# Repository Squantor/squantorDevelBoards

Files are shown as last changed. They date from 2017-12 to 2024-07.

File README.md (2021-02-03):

# Various development boards
This project contains a bunch of various development boards I use in my projects. They are usually focused on learning how to use a specific type of microcontroller or application.
## Nuclone development board series
As the name implies they resemble the [ST nucleo](https://www.st.com/en/evaluation-tools/stm32-nucleo-boards.html) in shape and function, minimal evaluation boards with all pins broken out and lot of jumpers.
## Structure
* [electronics](electronics/) contains the various nuclone examples, they are mostly [LPC microcontrollers](https://www.nxp.com/products/processors-and-microcontrollers/arm-microcontrollers/general-purpose-mcus:GENERAL-PURPOSE-MCUS) from [NXP](https://www.nxp.com/) but a few STM32's, nordic and holtek ARM microcontrollers are planned too.
* [software](software/) some example projects or project templates
* [mechanical](mechanical/) contains drawings for project boxes of the nuclone boards
## Checking out
This project makes extensive use of submodules, use ```git clone --recurse-submodules https://github.com/Squantor/squantorDevelBoards.git``` to clone the repository and its submodules in one go.

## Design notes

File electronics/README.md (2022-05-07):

# Development board electronics
Stored here is the electronics for various development boards I use. Most are based on the "nuclone" principle. They look a lot like the STM32 nucleo series development boards.
## List of boards
* [nuclone board for the LPC804M101JHI33](nuclone_LPC804M101JHI33/README.md) is a breakout for the LPC804M101JHI33 microcontroller.
* [nuclone board for the LPC812M101JDH20](nuclone_LPC812M101JDH20/README.md) is a breakout for the LPC812M101JDH20 microcontroller.
* [nuclone board for the LPC824M201JDH20](nuclone_LPC824M201JDH20/README.md) is a breakout for the LPC824M201JDH20 microcontroller.
* [nuclone board for the LPC824M201JHI33](nuclone_LPC824M201JHI33/README.md) is a breakout for the LPC824M201JHI33 microcontroller.
* [nuclone board for the LPC844M201BD64](nuclone_LPC844M201BD64/README.md) is a breakout for the LPC844M201BD64 microcontroller.
* [nuclone board for the LPC845M301JBD48](nuclone_LPC845M301JBD48/README.md) is a breakout for the LPC845M301JBD48 microcontroller.
* [nuclone board for the LPC1114JBD48](nuclone_LPC1114JBD48/README.md) is a breakout for the LPC1114JBD48 microcontroller.
* [nuclone board for the LPC1125JBD48](nuclone_LPC1125JBD48/README.md) is a breakout for the LPC1125JBD48 microcontroller.
* [nuclone board for the STM32F030C8T6](nuclone_STM32F030C8T6/README.md) is a breakout for the STM32F030C8T6 microcontroller.
* [nuclone board for the STM32F030K6](nuclone_STM32F030K6/README.md) is a breakout for the STM32F030K6 microcontroller.
* [nuclone board for the STM32F031K6](nuclone_STM32F031K6/README.md) is a breakout for the STM32F031K6 microcontroller.
* [small nuclone universal expansion board with USB to UART and prototyping area](nuclone_small_uart_expansion/README.md).
* [LPC824M201JHI33 nuclone expansion board with SD card slot](nuclone_LPC824M201JHI33_expansion_microSD_card/README.md).
* [LPC824M201JHI33 nuclone expansion board with SOIC NOR Flash](nuclone_LPC824M201JHI33_expansion_serial_flash_SOIC/README.md).
* [LPC824M201JHI33 nuclone expansion board with USON NOR Flash](nuclone_LPC824M201JHI33_expansion_serial_flash_USON/README.md).
* [LPC824M201JHI33 nuclone expansion board with wearable prototyping circuit](nuclone_LPC824M201JHI33_expansion_wearable/README.md). This contains a battery charger, serial flash for datalogging, usb connection for data download and a few sensors like accelerometer, ambient light and a few more. (WIP)

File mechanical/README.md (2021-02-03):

# Squantor Development boards mechanical components
Here reside the mechanical components the squantor development boards
## Descriptions
* [Small nuclone box base](small_nuclone_base_plate/): base plate for the small sized nuclone boards.
* Small nuclone box cover low: cover going over the small nuclone box base, having holes for the pin headers.
* Small nuclone box cover medium: cover going over the small nuclone box base, higher to accomodate one expansion board.
* Medium nuclone box base: base plate for the medium sized nuclone boards.
* Medium nuclone box cover low: cover going over the medium nuclone box base, having holes for the pin headers.
* Medium nuclone box cover medium: cover going over the medium nuclone box base, higher to accomodate one expansion board.

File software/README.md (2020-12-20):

# Squantor Development board software
Here are all the software projects used to exercise, test and just use the squantor development boards. The nuclone boards in particular.
## Project list
Here is a list of the various projects.
* LPC824_template: template project used for LPC824 microcontrollers, handy copy and paste reference
* nuclone_LPC824M201JHI33_expansion_serial_flash: demonstrator project for using the serial flash expansion board on a nuclone LPC824M201JHI33 development board
* PC: empty PC template
## Compiling
There are multiple projects present in this directory. Invoking compilation of any project is done with the ```PROJECT``` variable that needs to be passed on, see the following example:
```
make PROJECT=LPC824_template
```
Building can be done with various configurations that set up flags and other settings, this configuration is set with the ```CONFIG``` variable. Most projects have the ```release``` and ```debug``` where the ```debug``` configuration is default.
The ```release``` configuration has optimizations enabled (usually for size) and minimal included debugging information. The ```debug``` configuration has NO optimization and full debugging information. There might be specific configurations available per project. When no ```CONFIG``` is defined the default is the ```debug``` configuration.
### Debugging embedded projects
For debugging on embedded targets, the [Black Magic Probe](https://github.com/blacksphere/blackmagic/wiki) is used, scripts to use this debugger are present in the ```gdb_scripts``` directory. make can be used to invoke debugging:
```
make PROJECT=LPC824_template gdbbmp
```
If a build is needed, it is done automatically.
```
make tpwrdisable
make tpwrenable
```
The black magic probe is capable of powering the target, these commands enable/disable this function.
### Depedencies
The templates have a few dependencies that are automatically cloned when you do a clone with ```--recurses-submodules
* squantorLibC for minimal LibC functionality
* squantorLibEmbeddedC for various embedded helper functions
* squantorLibEmbedded newer embedded helper functions library
## Usage
To use the software you need the following hardware:
* [Black magic probe](https://github.com/blacksphere/blackmagic)
* Describe additional electronics prerequisites
# Additional information
If the project needs further explanation like commands, theory of operation or something else, Describe it here.
# TODO
Open tasks still to complete.
* completing this readme

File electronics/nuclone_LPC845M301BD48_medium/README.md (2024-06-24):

# medium nuclone board LPC845 PQFP48
Medium sized nuclone board LPC845 PQFP48
## TODO's
Still some things need to be done:
* schematic entry 
* PCB layout
* Review with one night in between
* Produce at [OSHPARK](https://oshpark.com/)
* Assemble
* Test & characterise
* update Readme.md with pictures and BOM
## BOM

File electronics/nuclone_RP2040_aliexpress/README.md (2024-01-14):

# nuclone raspberry pi pico
Medium sized nuclone fitted with a raspberry pi pico soldered on board, the pico micro USB is used as the board connection.
# HSI (Hardware Software Interface)
## TODO's
Still some things need to be done:
* schematic entry 
* PCB layout
* Review with one night in between
* Produce at [OSHPARK](https://oshpark.com/)
* Assemble
* Test & characterise
* update Readme.md with pictures and BOM
## BOM
* Raspberry pi pico
## Pictures

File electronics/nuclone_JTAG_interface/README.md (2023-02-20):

# Nuclone JTAG interface
Nuclone JTAG interface
# HSI (Hardware Software Interface)
You need to hook up the wanted pins to the nuclone pins, below is a list of test points you can connect to.
* UART RX
* UART TX
TODO JTAG
## TODO's
Still some things need to be done:
* Fill in this project description
* schematic entry 
* PCB layout
* Review with one night in between
* Produce at [aisler](https://aisler.net/)
* Assemble
* Test & characterise
* update Readme.md with pictures and BOM
## BOM
* TODO 1 bit dual supply level shifter
## Pictures
TODO

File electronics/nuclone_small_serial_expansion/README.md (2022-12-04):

# Nuclone expansion board with FTDI/UART connection
Nuclone expansion board with UART connection, prototyping area and some connections
# HSI (Hardware Software Interface)
No real HSI, UART RX/TX brought outside
## TODO's
Still some things need to be done:
* schematic entry 
* PCB layout
* Review with one night in between
* Produce at [OSHPARK](https://oshpark.com/)
* Assemble
* Test & characterise
* update Readme.md with pictures and BOM
## BOM
* bunch of JST-PH connectors

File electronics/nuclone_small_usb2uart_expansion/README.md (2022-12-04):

# Nuclone UART, JST expansion board
Nuclone expansion board with UART, prototyping area and some connections
# HSI (Hardware Software Interface)
No real HSI to speak about.
## TODO's
Still some things need to be done:
* update Readme.md with pictures and BOM
## BOM
This is a list of hardware components. If just mentioned a generic component like a 1K 0402 resistor, just name it as such, free to substitute. If you need some special integrated IC's show some sources like Mouser, Digikey, Farnell, or LCSC
* CH340B USB to serial converter

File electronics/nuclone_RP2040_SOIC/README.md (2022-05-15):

# RP2040 Nuclone board
Nuclone board for the RP2040 microcontroller
# HSI (Hardware Software Interface)
TODO
## TODO's
Still some things need to be done:
* schematic entry 
* fill in HSI
* PCB layout
* Review with one night in between
* Production
* Assemble
* Test & characterise
* update Readme.md with pictures and BOM
## BOM
* RP2040 microcontroller
* USB-C connector for USB 2.0

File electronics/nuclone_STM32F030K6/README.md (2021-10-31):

# Nuclone development board for STM32F030K6
STM32F030K6 development board inspired by the nucleo series from STM32.
## TODO's
Still some things need to be done:
* Review with one night in between (Done)
* Produce at [JLCPCB](https://jlcpcb.com/) (Done)
* Assemble (Done)
* Test & characterise (WIP)
* update Readme.md with pictures and BOM (WIP)

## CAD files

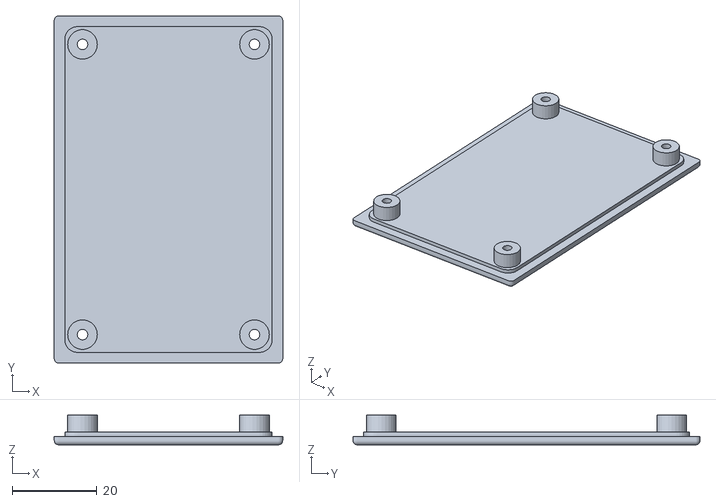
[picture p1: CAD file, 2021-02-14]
mechanical/medium_nuclone_base_plate/medium_nuclone_base_plate_m3_tapping.stl
54.0 x 82.0 x 7.00

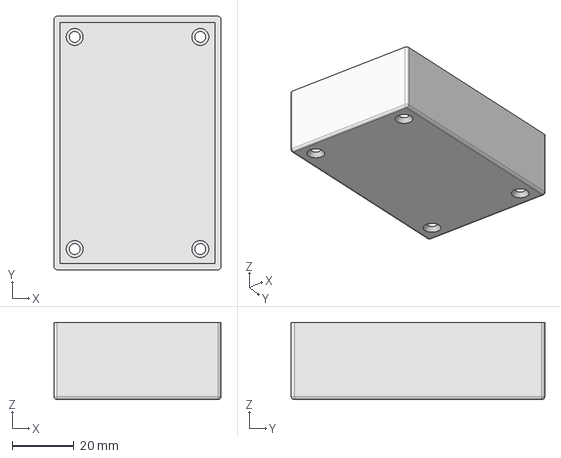
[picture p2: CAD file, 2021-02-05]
mechanical/medium_nuclone_cover_expansion/medium_nuclone_cover_expansion.FCStd
54.0 x 82.0 x 25.0 mm

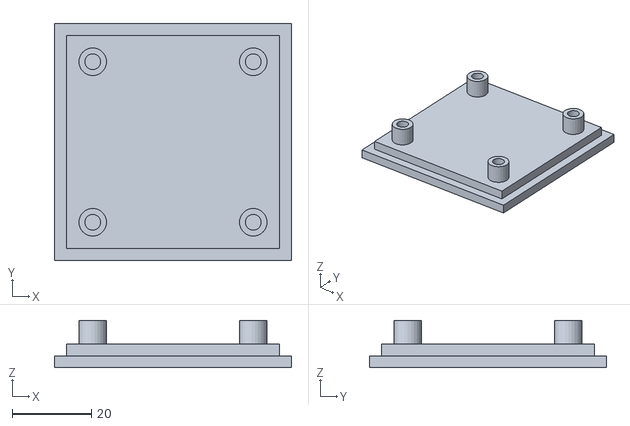
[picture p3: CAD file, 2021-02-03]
mechanical/small_nuclone_base_plate/small_nuclone_base_plate_m3_insert.stl
60.0 x 60.0 x 12.0

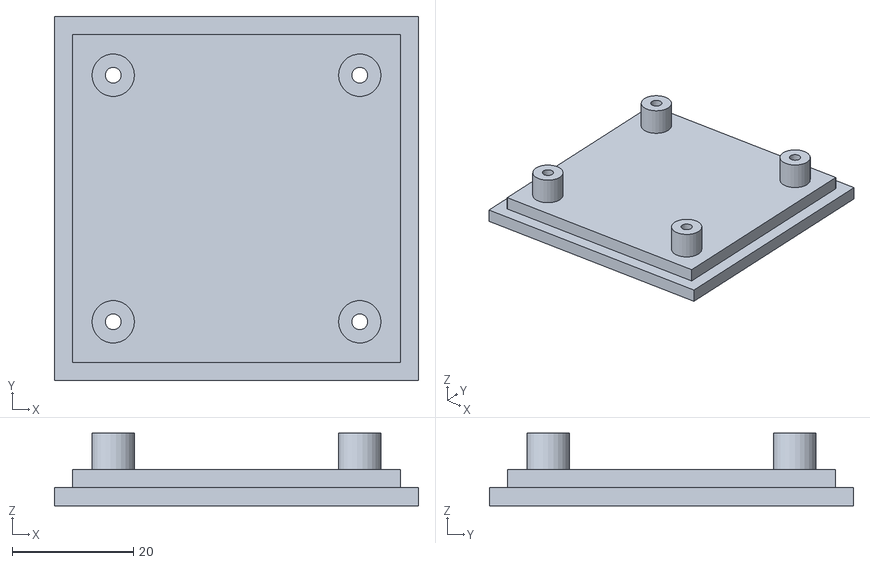
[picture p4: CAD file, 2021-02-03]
mechanical/small_nuclone_base_plate/small_nuclone_base_plate_m3_tap.stl
60.0 x 60.0 x 12.0

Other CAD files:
mechanical/medium_nuclone_base_plate/medium_nuclone_base_plate.FCStd
mechanical/small_nuclone_base_plate/small_nuclone_base_plate.FCStd
mechanical/medium_nuclone_cover_expansion/medium_nuclone_cover_expansion.stl

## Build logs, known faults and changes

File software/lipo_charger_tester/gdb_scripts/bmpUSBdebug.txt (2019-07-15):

file bin/debug/lipo_charger_tester.elf
target extended-remote /dev/ttyBmpGdb0
monitor tpwr enable
shell sleep 1
monitor swdp_scan
attach 1
set mem inaccessible-by-default off
set {int}0x40048000 = 2
load bin/debug/lipo_charger_tester.elf
set {int}0x40048000 = 2
compare-sections
b main

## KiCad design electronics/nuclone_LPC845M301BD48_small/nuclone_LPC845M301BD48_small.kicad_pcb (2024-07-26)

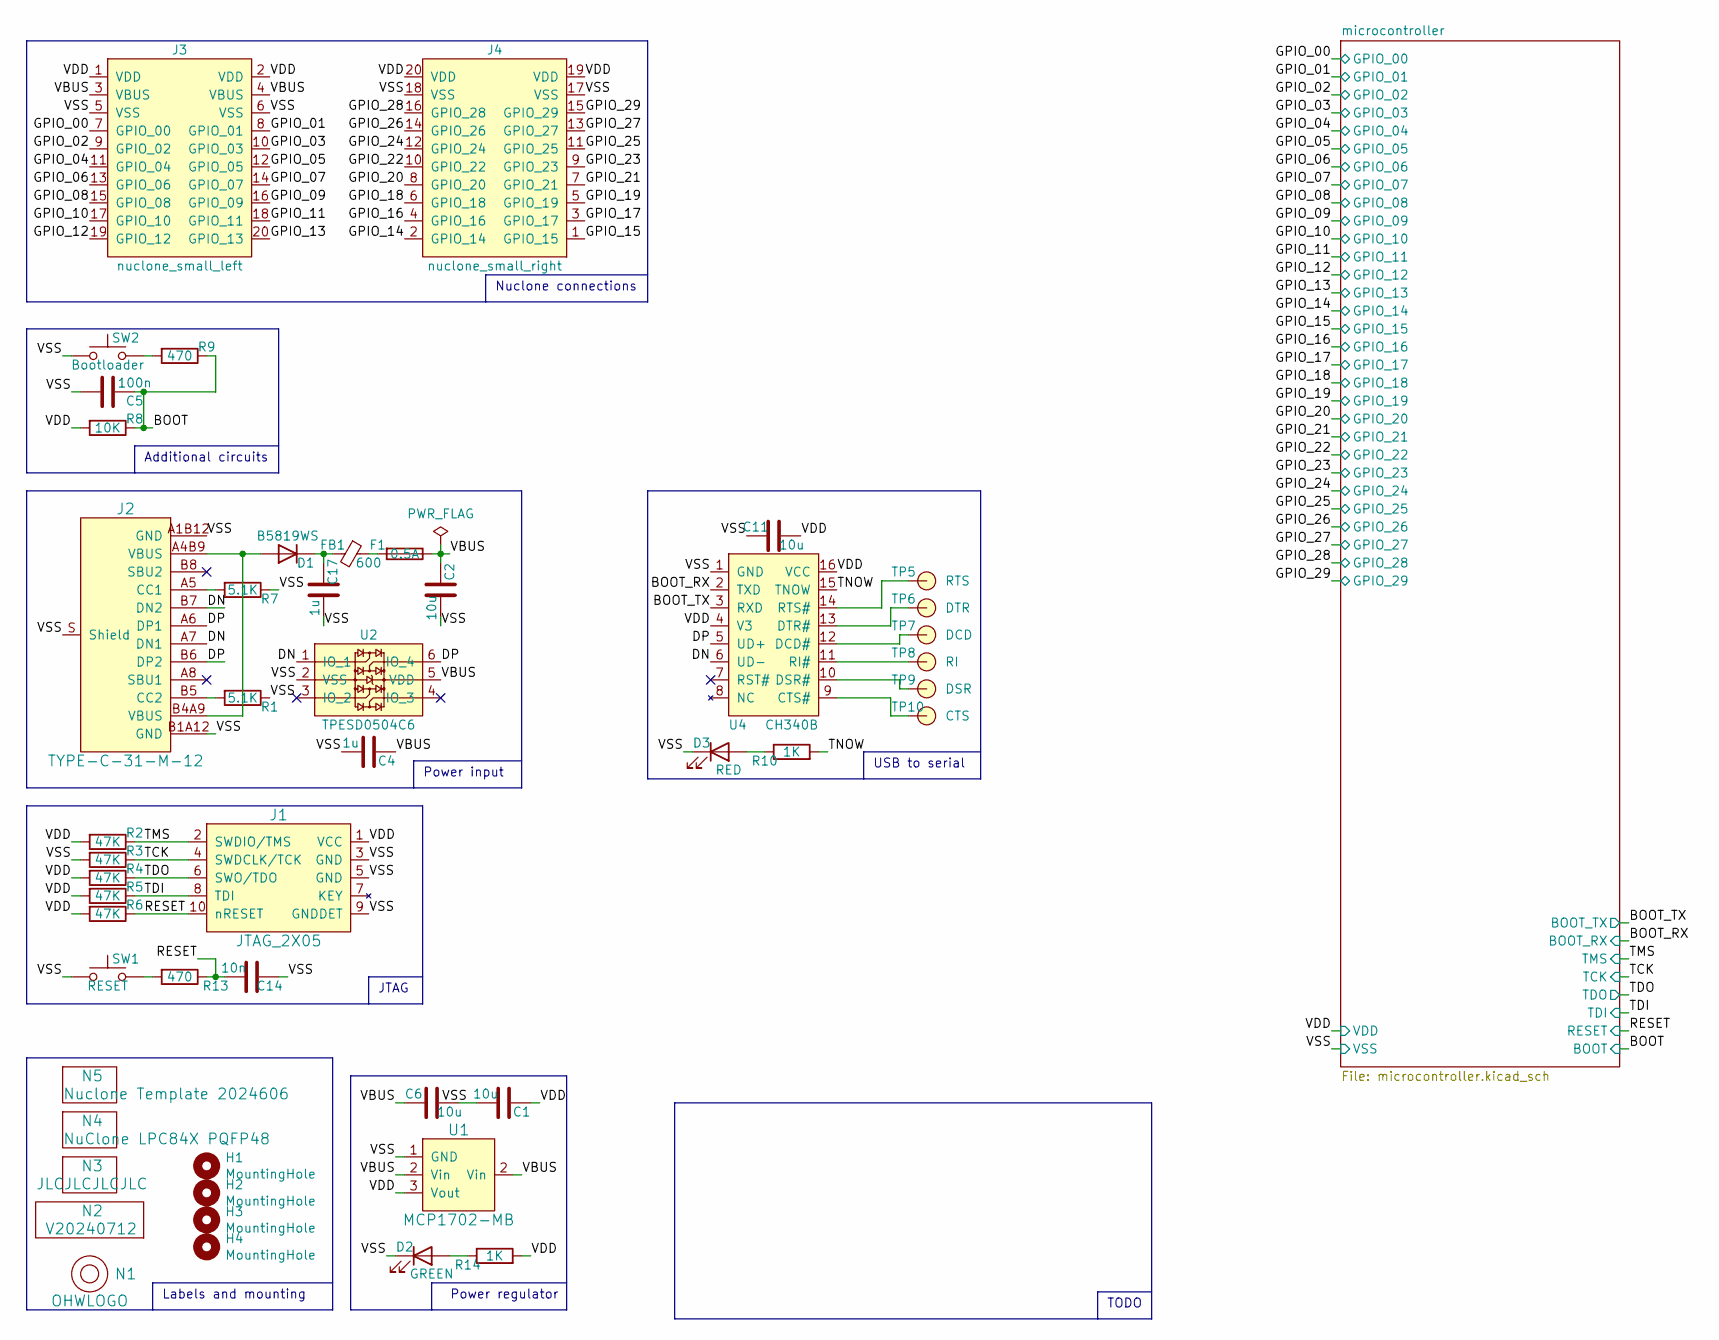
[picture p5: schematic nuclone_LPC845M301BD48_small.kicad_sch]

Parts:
C1, C2, C6, C11: 10u; C_0603
C4, C17: 1u; C_0603
C5: 100n; C_0603
C14: 10n; C_0603
D1: B5819WS; SOD-323-nexperia-hand
D2: GREEN; LED_0603_hand
D3: RED; LED_0603_hand
F1: 0.5A; F_0603_hand
FB1: 600; L_0603
H1, H2, H3, H4: MountingHole; MountingHole_3.2mm_M3_Pad_Via
J1: JTAG_2X05; Header-0127-2X05-H006
J2: TYPE-C-31-M-12; USB-C-HRO-31-M-12
J3: nuclone_small_left; nuclone_small_left_stacked
J4: nuclone_small_right; nuclone_small_right_stacked
N1: OHWLOGO; OSHW-Symbol_6.7x6mm_SilkScreen
N2: V20240712; Label_Generic
N3: JLCJLCJLCJLC; Label_Generic
N4: NuClone LPC84X PQFP48; Label_Generic
N5: Nuclone Template 2024606; Label_Generic
R1, R7: 5.1K; R_0603_hand
R2, R3, R4, R5, R6: 47K; R_0603_hand
R8: 10K; R_0603_hand
R9, R13: 470; R_0603_hand
R10, R14: 1K; R_0603_hand
SW1: RESET; TD-85XU
SW2: Bootloader; TD-85XU
TP5: RTS; TestPoint_hole_H05R10
TP6: DTR; TestPoint_hole_H05R10
TP7: DCD; TestPoint_hole_H05R10
TP8: RI; TestPoint_hole_H05R10
TP9: DSR; TestPoint_hole_H05R10
TP10: CTS; TestPoint_hole_H05R10
U1: MCP1702-MB; SOT89-NXP
U2: TPESD0504C6; SOT363-ONsemi
U4: CH340B; SOIC-16_3.9x9.9mm_P1.27mm

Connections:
/BOOT: C5.1, R8.1, R9.1; also elsewhere on the board
/BOOT_RX: U4.2 (TXD); also elsewhere on the board
/BOOT_TX: U4.3 (RXD); also elsewhere on the board
/DN: J2.A7 (DN1), J2.B7 (DN2), U2.1 (IO_1), U4.6 (UD-)
/DP: J2.A6 (DP1), J2.B6 (DP2), U2.6 (IO_4), U4.5 (UD+)
/GPIO_00: J3.7 (GPIO_00); also elsewhere on the board
/GPIO_01: J3.8 (GPIO_01); also elsewhere on the board
/GPIO_02: J3.9 (GPIO_02); also elsewhere on the board
/GPIO_03: J3.10 (GPIO_03); also elsewhere on the board
/GPIO_04: J3.11 (GPIO_04); also elsewhere on the board
/GPIO_05: J3.12 (GPIO_05); also elsewhere on the board
/GPIO_06: J3.13 (GPIO_06); also elsewhere on the board
/GPIO_07: J3.14 (GPIO_07); also elsewhere on the board
/GPIO_08: J3.15 (GPIO_08); also elsewhere on the board
/GPIO_09: J3.16 (GPIO_09); also elsewhere on the board
/GPIO_10: J3.17 (GPIO_10); also elsewhere on the board
/GPIO_11: J3.18 (GPIO_11); also elsewhere on the board
/GPIO_12: J3.19 (GPIO_12); also elsewhere on the board
/GPIO_13: J3.20 (GPIO_13); also elsewhere on the board
/GPIO_14: J4.2 (GPIO_14); also elsewhere on the board
/GPIO_15: J4.1 (GPIO_15); also elsewhere on the board
/GPIO_16: J4.4 (GPIO_16); also elsewhere on the board
/GPIO_17: J4.3 (GPIO_17); also elsewhere on the board
/GPIO_18: J4.6 (GPIO_18); also elsewhere on the board
/GPIO_19: J4.5 (GPIO_19); also elsewhere on the board
/GPIO_20: J4.8 (GPIO_20); also elsewhere on the board
/GPIO_21: J4.7 (GPIO_21); also elsewhere on the board
/GPIO_22: J4.10 (GPIO_22); also elsewhere on the board
/GPIO_23: J4.9 (GPIO_23); also elsewhere on the board
/GPIO_24: J4.12 (GPIO_24); also elsewhere on the board
/GPIO_25: J4.11 (GPIO_25); also elsewhere on the board
/GPIO_26: J4.14 (GPIO_26); also elsewhere on the board
/GPIO_27: J4.13 (GPIO_27); also elsewhere on the board
/GPIO_28: J4.16 (GPIO_28); also elsewhere on the board
/GPIO_29: J4.15 (GPIO_29); also elsewhere on the board
/RESET: C14.2, J1.10 (nRESET), R6.1, R13.1; also elsewhere on the board
/TCK: J1.4 (SWDCLK/TCK), R3.1; also elsewhere on the board
/TDI: J1.8 (TDI), R5.1
/TDO: J1.6 (SWO/TDO), R4.1
/TMS: J1.2 (SWDIO/TMS), R2.1; also elsewhere on the board
/TNOW: R10.2, U4.15 (TNOW)
/VBUS: C2.2, C4.1, C6.1, F1.1, J3.3 (VBUS), J3.4 (VBUS), U1.2 (Vin), U2.5 (VDD)
/VDD: C1.1, C11.1, J1.1 (VCC), J3.1 (VDD), J3.2 (VDD), J4.19 (VDD), J4.20 (VDD), R2.2, R4.2, R5.2, R6.2, R8.2, R14.2, U1.3 (Vout), U4.4 (V3), U4.16 (VCC); also elsewhere on the board
/VSS: C1.2, C2.1, C4.2, C5.2, C6.2, C11.2, C14.1, C17.1, D2.1 (K), D3.1 (K), J1.3 (GND), J1.5 (GND), J1.9 (GNDDET), J2.A1B12 (GND), J2.B1A12 (GND), J2.S (Shield), J3.5 (VSS), J3.6 (VSS), J4.17 (VSS), J4.18 (VSS), R1.1, R3.2, R7.1, SW1.1, SW2.1, U1.1 (GND), U2.2 (VSS), U4.1 (GND); also elsewhere on the board
unnamed: D1.2 (A), J2.A4B9 (VBUS), J2.B4A9 (VBUS)
unnamed: C17.2, D1.1 (K), FB1.2
unnamed: D2.2 (A), R14.1
unnamed: D3.2 (A), R10.1
unnamed: F1.2, FB1.1
unnamed: J2.A5 (CC1), R7.2
unnamed: J2.B5 (CC2), R1.2
unnamed: R9.2, SW2.2
unnamed: R13.2, SW1.2
unnamed: TP10.1, U4.9 (CTS#)
unnamed: TP7.1, U4.12 (DCD#)
unnamed: TP9.1, U4.10 (DSR#)
unnamed: TP6.1, U4.13 (DTR#)
unnamed: TP8.1, U4.11 (RI#)
unnamed: TP5.1, U4.14 (RTS#)

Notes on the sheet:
Power input
Nuclone connections
USB to serial
Additional circuits
TODO
Power regulator
Labels and mounting
JTAG

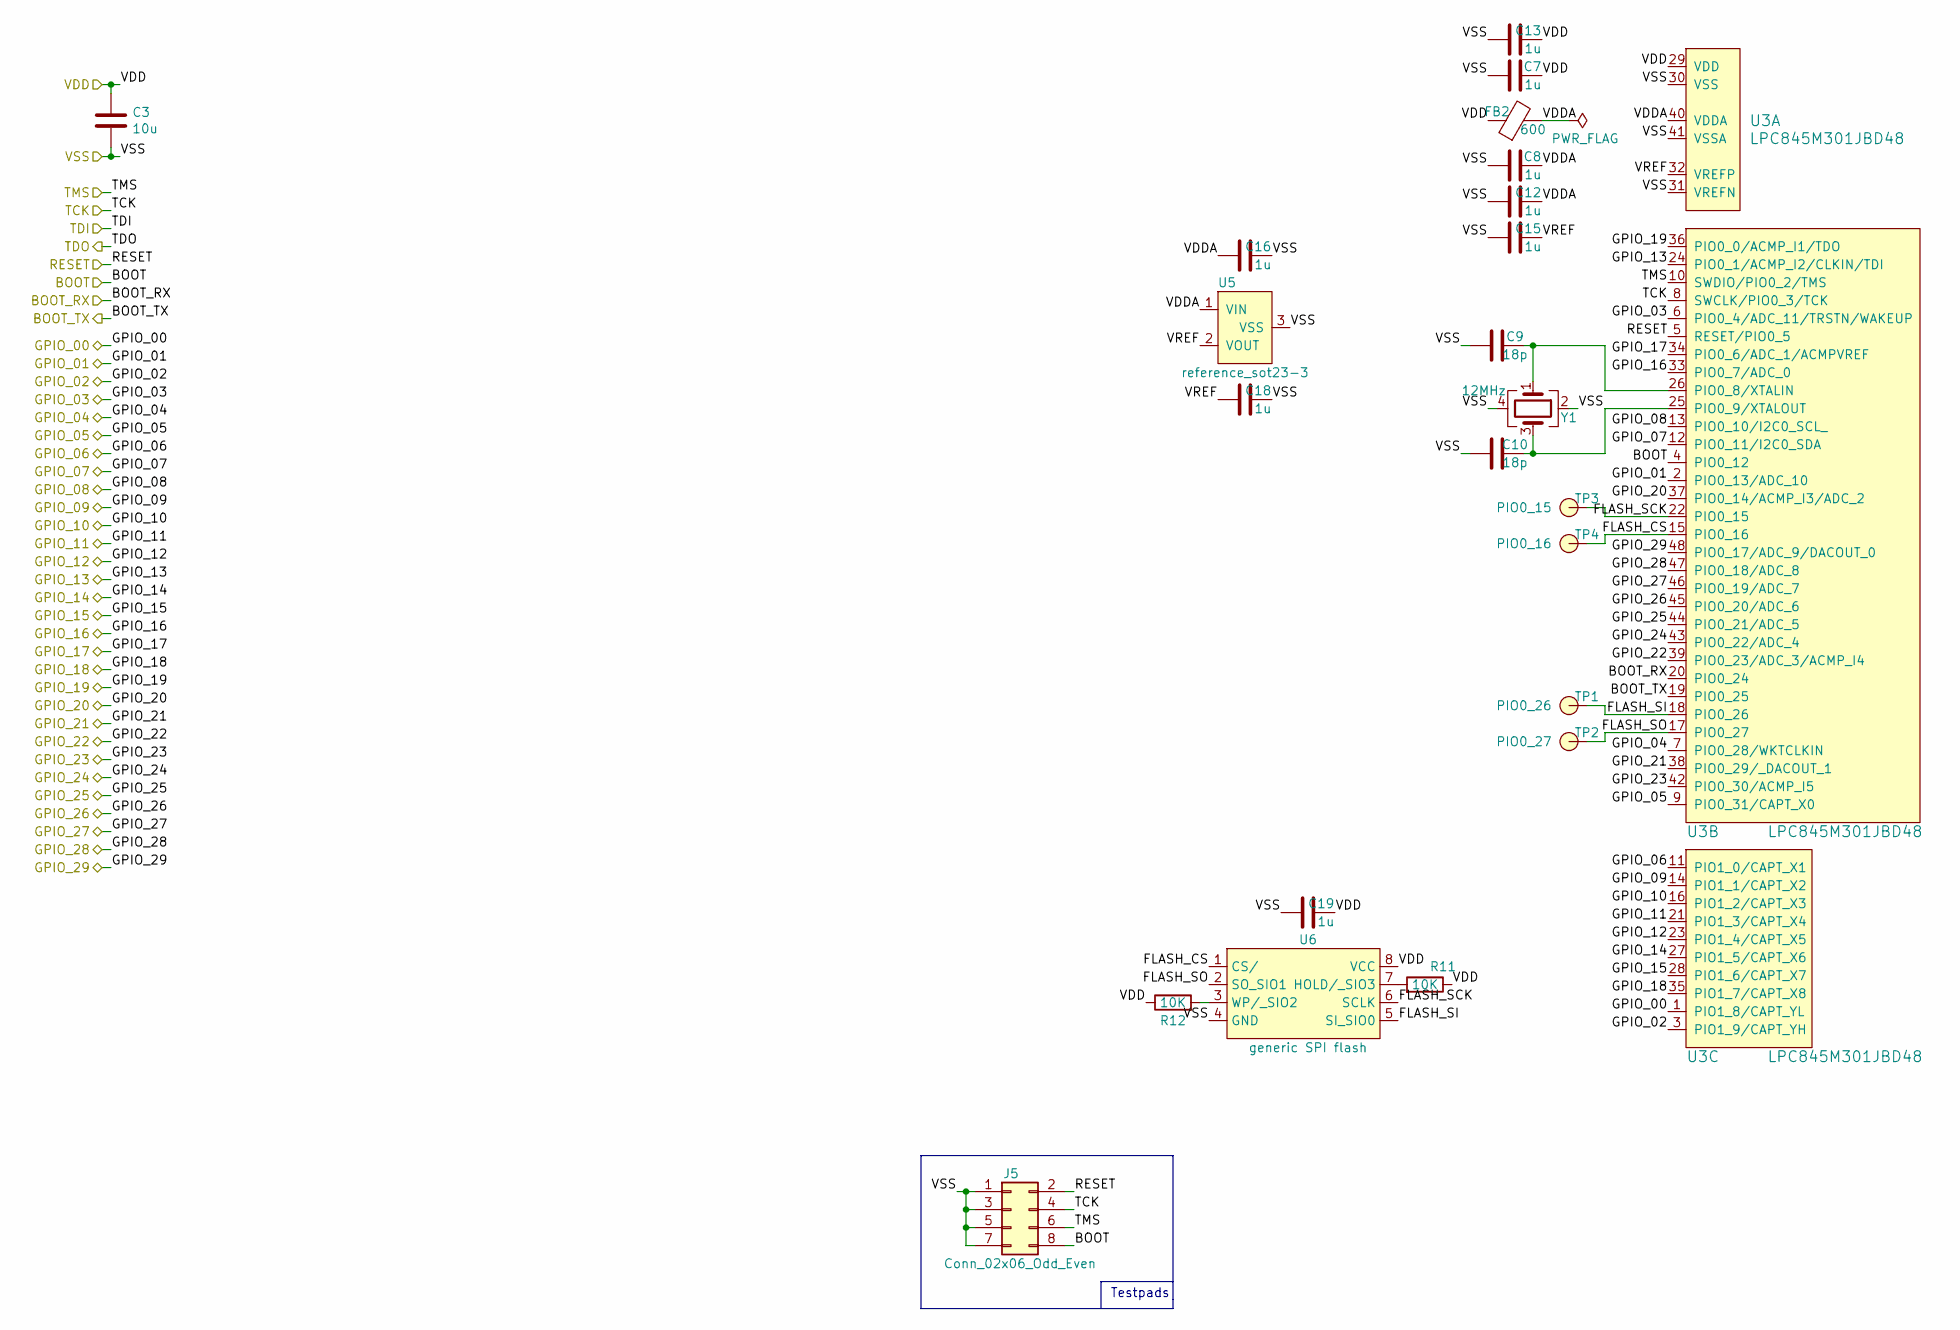
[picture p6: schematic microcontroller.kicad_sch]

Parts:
C3: 10u; C_0603
C7, C8, C16, C18, C19: 1u; C_0603
C9, C10: 18p; C_0603
C12, C13, C15: 1u; C_0402
FB2: 600; L_0603
J5: Conn_02x06_Odd_Even; Header-0127-2X04-H006
R11, R12: 10K; R_0603_hand
TP1: PIO0_26; TestPoint_hole_H05R10
TP2: PIO0_27; TestPoint_hole_H05R10
TP3: PIO0_15; TestPoint_hole_H05R10
TP4: PIO0_16; TestPoint_hole_H05R10
U3: LPC845M301JBD48; SOT313-2-NXP
U5: reference_sot23-3; SOT23-3
U6: generic SPI flash; SOIC-8_dual_wide
Y1: 12MHz; Crystal_3225_4_hand

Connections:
/BOOT: J5.8, U3.4 (PIO0_12); also elsewhere on the board
/BOOT_RX: U3.20 (PIO0_24); also elsewhere on the board
/BOOT_TX: U3.19 (PIO0_25); also elsewhere on the board
/GPIO_00: U3.1 (PIO1_8/CAPT_YL); also elsewhere on the board
/GPIO_01: U3.2 (PIO0_13/ADC_10); also elsewhere on the board
/GPIO_02: U3.3 (PIO1_9/CAPT_YH); also elsewhere on the board
/GPIO_03: U3.6 (PIO0_4/ADC_11/TRSTN/WAKEUP); also elsewhere on the board
/GPIO_04: U3.7 (PIO0_28/WKTCLKIN); also elsewhere on the board
/GPIO_05: U3.9 (PIO0_31/CAPT_X0); also elsewhere on the board
/GPIO_06: U3.11 (PIO1_0/CAPT_X1); also elsewhere on the board
/GPIO_07: U3.12 (PIO0_11/I2C0_SDA); also elsewhere on the board
/GPIO_08: U3.13 (PIO0_10/I2C0_SCL_); also elsewhere on the board
/GPIO_09: U3.14 (PIO1_1/CAPT_X2); also elsewhere on the board
/GPIO_10: U3.16 (PIO1_2/CAPT_X3); also elsewhere on the board
/GPIO_11: U3.21 (PIO1_3/CAPT_X4); also elsewhere on the board
/GPIO_12: U3.23 (PIO1_4/CAPT_X5); also elsewhere on the board
/GPIO_13: U3.24 (PIO0_1/ACMP_I2/CLKIN/TDI); also elsewhere on the board
/GPIO_14: U3.27 (PIO1_5/CAPT_X6); also elsewhere on the board
/GPIO_15: U3.28 (PIO1_6/CAPT_X7); also elsewhere on the board
/GPIO_16: U3.33 (PIO0_7/ADC_0); also elsewhere on the board
/GPIO_17: U3.34 (PIO0_6/ADC_1/ACMPVREF); also elsewhere on the board
/GPIO_18: U3.35 (PIO1_7/CAPT_X8); also elsewhere on the board
/GPIO_19: U3.36 (PIO0_0/ACMP_I1/TDO); also elsewhere on the board
/GPIO_20: U3.37 (PIO0_14/ACMP_I3/ADC_2); also elsewhere on the board
/GPIO_21: U3.38 (PIO0_29/_DACOUT_1); also elsewhere on the board
/GPIO_22: U3.39 (PIO0_23/ADC_3/ACMP_I4); also elsewhere on the board
/GPIO_23: U3.42 (PIO0_30/ACMP_I5); also elsewhere on the board
/GPIO_24: U3.43 (PIO0_22/ADC_4); also elsewhere on the board
/GPIO_25: U3.44 (PIO0_21/ADC_5); also elsewhere on the board
/GPIO_26: U3.45 (PIO0_20/ADC_6); also elsewhere on the board
/GPIO_27: U3.46 (PIO0_19/ADC_7); also elsewhere on the board
/GPIO_28: U3.47 (PIO0_18/ADC_8); also elsewhere on the board
/GPIO_29: U3.48 (PIO0_17/ADC_9/DACOUT_0); also elsewhere on the board
/RESET: J5.2, U3.5 (RESET/PIO0_5); also elsewhere on the board
/TCK: J5.4, U3.8 (SWCLK/PIO0_3/TCK); also elsewhere on the board
/TMS: J5.6, U3.10 (SWDIO/PIO0_2/TMS); also elsewhere on the board
/VDD: C3.1, C7.2, C13.2, C19.2, FB2.1, R11.1, R12.1, U3.29 (VDD), U6.8 (VCC); also elsewhere on the board
/VSS: C3.2, C7.1, C8.1, C9.2, C10.2, C12.1, C13.1, C15.1, C16.2, C18.2, C19.1, J5.1, J5.3, J5.5, J5.7, U3.30 (VSS), U3.31 (VREFN), U3.41 (VSSA), U5.3 (VSS), U6.4 (GND), Y1.2, Y1.4; also elsewhere on the board
/microcontroller/FLASH_CS: TP4.1, U3.15 (PIO0_16), U6.1 (CS/)
/microcontroller/FLASH_SCK: TP3.1, U3.22 (PIO0_15), U6.6 (SCLK)
/microcontroller/FLASH_SI: TP1.1, U3.18 (PIO0_26), U6.5 (SI_SIO0)
/microcontroller/FLASH_SO: TP2.1, U3.17 (PIO0_27), U6.2 (SO_SIO1)
/microcontroller/VDDA: C8.2, C12.2, C16.1, FB2.2, U3.40 (VDDA), U5.1 (VIN)
/microcontroller/VREF: C15.2, C18.1, U3.32 (VREFP), U5.2 (VOUT)
unnamed: C9.1, U3.26 (PIO0_8/XTALIN), Y1.1
unnamed: C10.1, U3.25 (PIO0_9/XTALOUT), Y1.3
unnamed: R11.2, U6.7 (HOLD/_SIO3)
unnamed: R12.2, U6.3 (WP/_SIO2)

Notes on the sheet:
Testpads

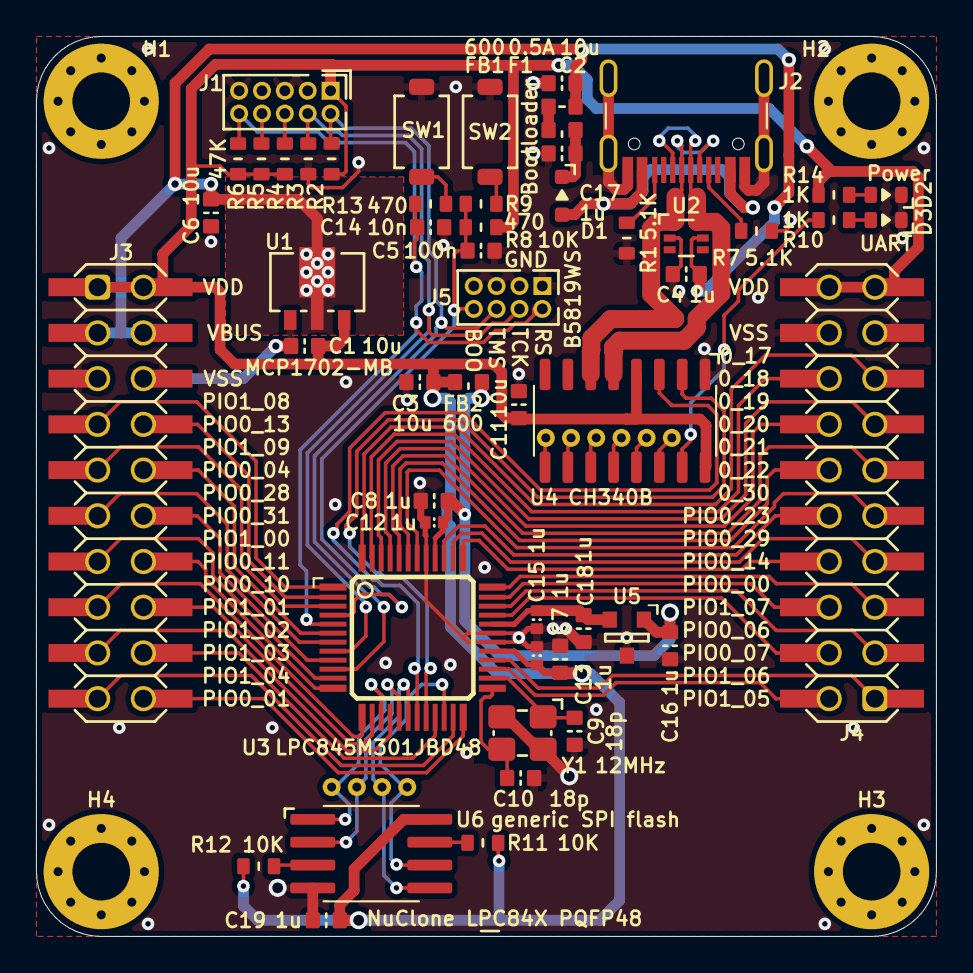
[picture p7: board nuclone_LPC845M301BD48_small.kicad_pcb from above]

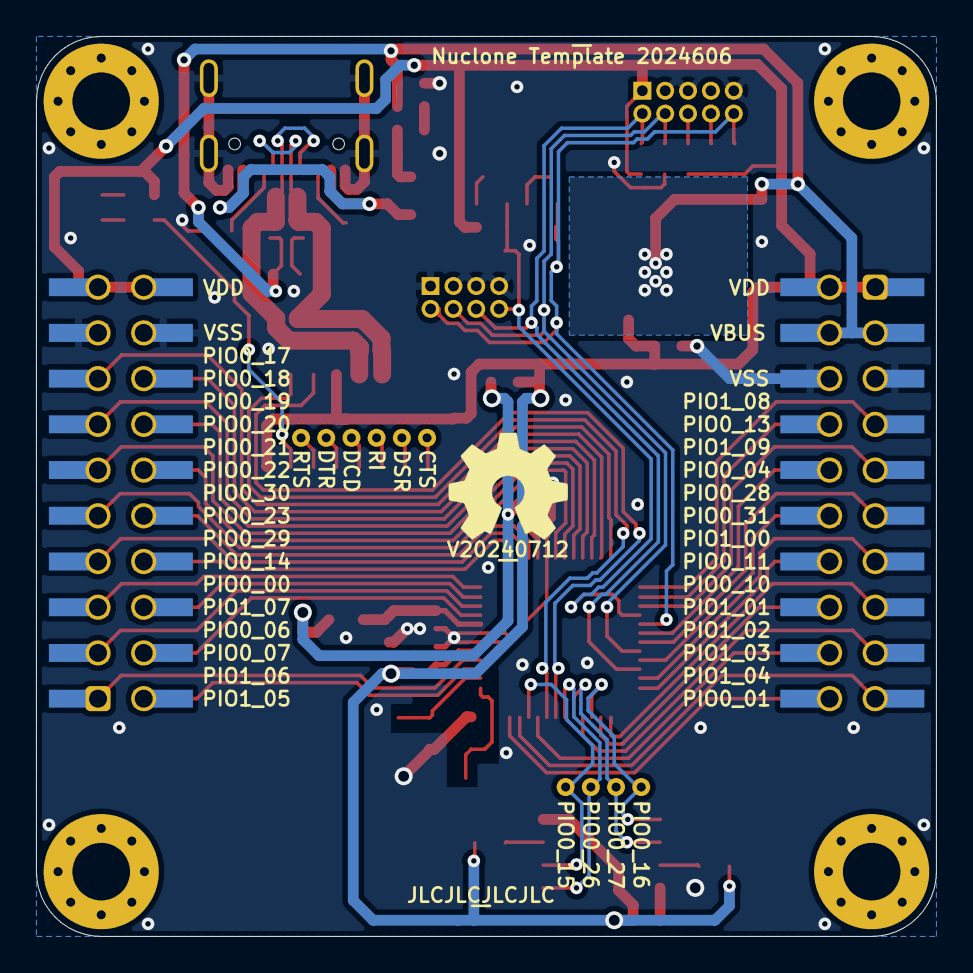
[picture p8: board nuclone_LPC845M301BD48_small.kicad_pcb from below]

Board: 2 copper layers, 50.0 x 50.0 mm, 72 parts (14 on the bottom side), 69 nets.

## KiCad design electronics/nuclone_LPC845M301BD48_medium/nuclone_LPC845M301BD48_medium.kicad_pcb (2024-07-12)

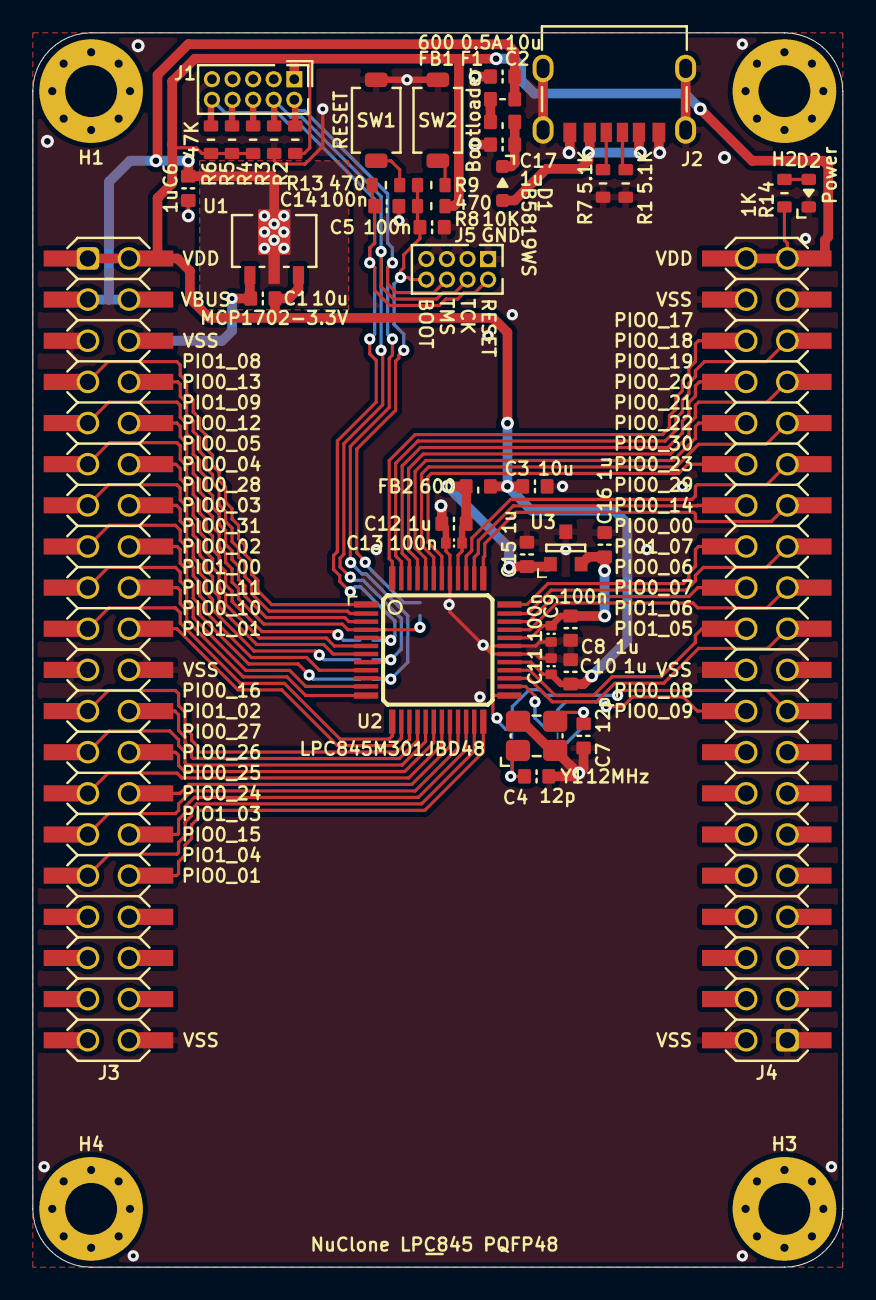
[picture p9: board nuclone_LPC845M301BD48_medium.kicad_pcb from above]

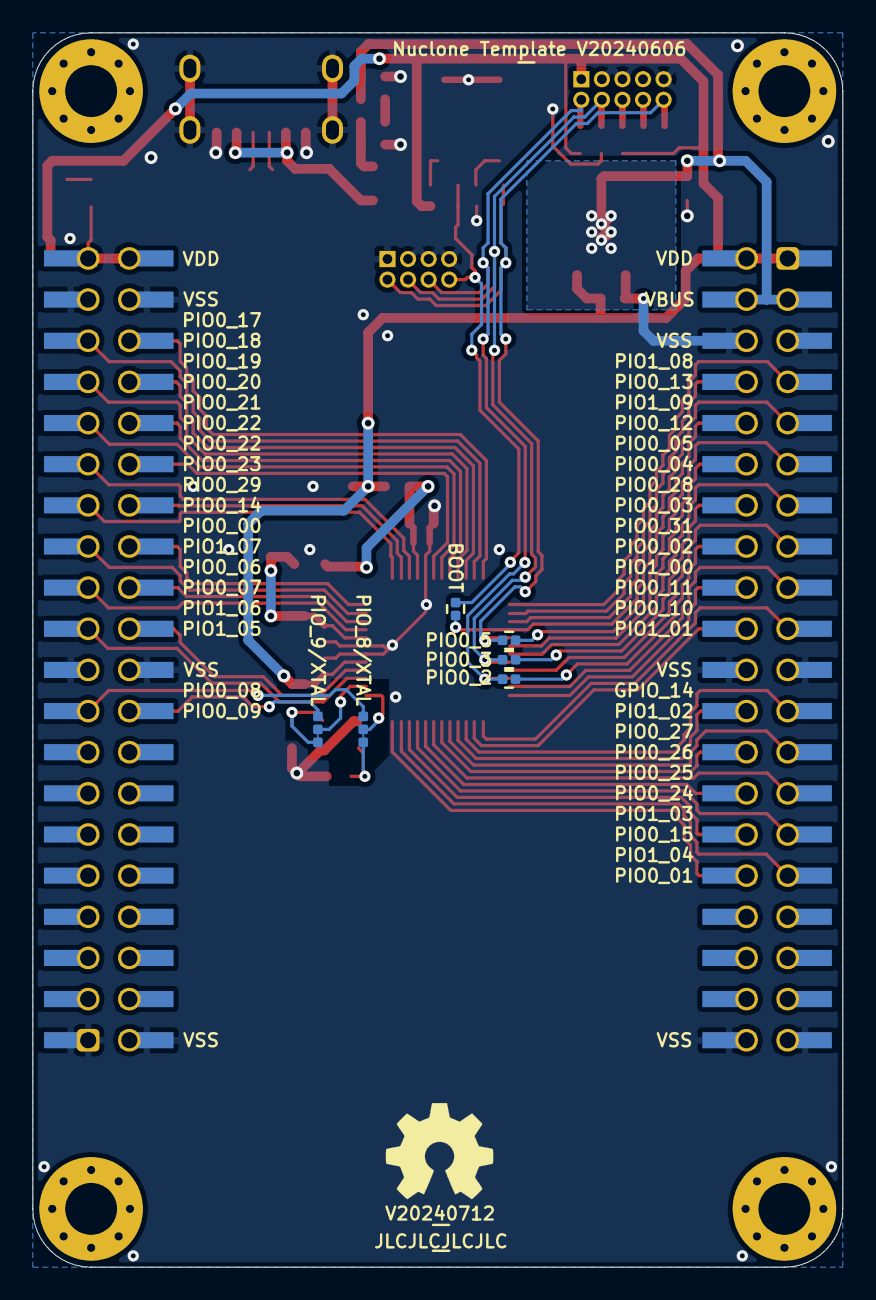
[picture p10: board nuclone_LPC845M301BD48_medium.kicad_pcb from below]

Board: 2 copper layers, 50.0 x 76.2 mm, 59 parts (10 on the bottom side), 65 nets.

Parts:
C1, C2, C3: 10u; C_0603
C4, C7: 12p; C_0603
C5, C14: 100n; C_0603
C6, C8, C10, C12, C15, C16, C17: 1u; C_0603
C9, C11, C13: 100n; C_0402
D1: B5819WS; SOD-323-nexperia-hand
D2: GREEN; LED_0603_hand
F1: 0.5A; F_0603_hand
FB1, FB2: 600; L_0603
H1, H2, H3, H4: MountingHole; MountingHole_3.2mm_M3_Pad_Via
J1: JTAG_2X05; Header-0127-2X05-H006
J2: TYPE-C-31-M-12; USB-C-HRO-31-M-17_aisler
J3: nuclone_medium_left; nuclone_medium_left_stacked
J4: nuclone_medium_right; nuclone_medium_right_stacked
J5: Conn_02x06_Odd_Even; Header-0127-2X04-H006
JP1: BOOT; solder_jumper_0402_2way_noconn
JP3: PIO0_2; solder_jumper_0402_2way_noconn
JP4: PIO0_3; solder_jumper_0402_2way_noconn
JP5: PIO0_5; solder_jumper_0402_2way_noconn
JP6: PIO_8/XTAL; solder_jumper_0402_3way_12conn
JP7: PIO_9/XTAL; solder_jumper_0402_3way_12conn
N1: OHWLOGO; OSHW-Symbol_6.7x6mm_SilkScreen
N2: V20240712; Label_Generic
N3: JLCJLCJLCJLC; Label_Generic
N4: NuClone LPC845 PQFP48; Label_Generic
N5: Nuclone Template V20240606; Label_Generic
R1, R7: 5.1K; R_0603_hand
R2, R3, R4, R5, R6: 47K; R_0603_hand
R8: 10K; R_0603_hand
R9, R13: 470; R_0603_hand
R14: 1K; R_0603_hand
SW1: RESET; TD-85XU
SW2: Bootloader; TD-85XU
U1: MCP1702-3.3V; SOT89-NXP
U2: LPC845M301JBD48; SOT313-2-NXP
U3: reference_sot23-3; SOT23-3
Y1: 12MHz; Crystal_3225_4_hand

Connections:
/Bootloader: C5.1, J5.8, JP1.2, R8.1, R9.1
/GPIO_00: J3.7 (GPIO_00), U2.1 (PIO1_8/CAPT_YL)
/GPIO_01: J3.8 (GPIO_01), U2.2 (PIO0_13/ADC_10)
/GPIO_02: J3.9 (GPIO_02), U2.3 (PIO1_9/CAPT_YH)
/GPIO_03: J3.10 (GPIO_03), JP1.1, U2.4 (PIO0_12)
/GPIO_04: J3.11 (GPIO_04), JP5.1
/GPIO_05: J3.12 (GPIO_05), U2.6 (PIO0_4/ADC_11/TRSTN/WAKEUP)
/GPIO_06: J3.13 (GPIO_06), U2.7 (PIO0_28/WKTCLKIN)
/GPIO_07: J3.14 (GPIO_07), JP4.1
/GPIO_08: J3.15 (GPIO_08), U2.9 (PIO0_31/CAPT_X0)
/GPIO_09: J3.16 (GPIO_09), JP3.1
/GPIO_10: J3.17 (GPIO_10), U2.11 (PIO1_0/CAPT_X1)
/GPIO_11: J3.18 (GPIO_11), U2.12 (PIO0_11/I2C0_SDA)
/GPIO_12: J3.19 (GPIO_12), U2.13 (PIO0_10/I2C0_SCL_)
/GPIO_13: J3.20 (GPIO_13), U2.14 (PIO1_1/CAPT_X2)
/GPIO_14: J3.23 (GPIO_14), U2.15 (PIO0_16)
/GPIO_15: J3.24 (GPIO_15), U2.16 (PIO1_2/CAPT_X3)
/GPIO_16: J3.25 (GPIO_16), U2.17 (PIO0_27)
/GPIO_17: J3.26 (GPIO_17), U2.18 (PIO0_26)
/GPIO_18: J3.27 (GPIO_18), U2.19 (PIO0_25)
/GPIO_19: J3.28 (GPIO_19), U2.20 (PIO0_24)
/GPIO_20: J3.29 (GPIO_20), U2.21 (PIO1_3/CAPT_X4)
/GPIO_21: J3.30 (GPIO_21), U2.22 (PIO0_15)
/GPIO_22: J3.31 (GPIO_22), U2.23 (PIO1_4/CAPT_X5)
/GPIO_23: J3.32 (GPIO_23), U2.24 (PIO0_1/ACMP_I2/CLKIN/TDI)
/GPIO_44: J4.17 (GPIO_45), JP6.3
/GPIO_45: J4.18 (GPIO_44), JP7.3
/GPIO_46: J4.21 (GPIO_47), U2.27 (PIO1_5/CAPT_X6)
/GPIO_47: J4.22 (GPIO_46), U2.28 (PIO1_6/CAPT_X7)
/GPIO_48: J4.23 (GPIO_49), U2.33 (PIO0_7/ADC_0)
/GPIO_49: J4.24 (GPIO_48), U2.34 (PIO0_6/ADC_1/ACMPVREF)
/GPIO_50: J4.25 (GPIO_51), U2.35 (PIO1_7/CAPT_X8)
/GPIO_51: J4.26 (GPIO_50), U2.36 (PIO0_0/ACMP_I1/TDO)
/GPIO_52: J4.27 (GPIO_53), U2.37 (PIO0_14/ACMP_I3/ADC_2)
/GPIO_53: J4.28 (GPIO_52), U2.38 (PIO0_29/_DACOUT_1)
/GPIO_54: J4.29 (GPIO_55), U2.39 (PIO0_23/ADC_3/ACMP_I4)
/GPIO_55: J4.30 (GPIO_54), U2.42 (PIO0_30/ACMP_I5)
/GPIO_56: J4.31 (GPIO_57), U2.43 (PIO0_22/ADC_4)
/GPIO_57: J4.32 (GPIO_56), U2.44 (PIO0_21/ADC_5)
/GPIO_58: J4.33 (GPIO_59), U2.45 (PIO0_20/ADC_6)
/GPIO_59: J4.34 (GPIO_58), U2.46 (PIO0_19/ADC_7)
/GPIO_60: J4.35 (GPIO_61), U2.47 (PIO0_18/ADC_8)
/GPIO_61: J4.36 (GPIO_60), U2.48 (PIO0_17/ADC_9/DACOUT_0)
/RESET: C14.2, J1.10 (nRESET), J5.2, JP5.2, R6.1, R13.1, U2.5 (RESET/PIO0_5)
/TCK: J1.4 (SWDCLK/TCK), J5.4, JP4.2, R3.1, U2.8 (SWCLK/PIO0_3/TCK)
/TDI: J1.8 (TDI), R5.1
/TDO: J1.6 (SWO/TDO), R4.1
/TMS: J1.2 (SWDIO/TMS), J5.6, JP3.2, R2.1, U2.10 (SWDIO/PIO0_2/TMS)
/VBUS: C2.2, C6.2, F1.1, J3.3 (VBUS), J3.4 (VBUS), U1.2 (Vin)
/VDD: C1.1, C3.2, C10.1, C11.1, FB2.2, J1.1 (VCC), J3.1 (VDD), J3.2 (VDD), J4.39 (VDD), J4.40 (VDD), R2.2, R4.2, R5.2, R6.2, R8.2, R14.2, U1.3 (Vout), U2.29 (VDD)
/VSS: C1.2, C2.1, C3.1, C4.2, C5.2, C6.1, C7.2, C8.2, C9.2, C10.2, C11.2, C12.2, C13.2, C14.1, C15.2, C16.2, C17.1, D2.1 (K), J1.3 (GND), J1.5 (GND), J1.9 (GNDDET), J2.A12 (GND), J2.B12 (GND), J2.S (Shield), J3.5 (VSS), J3.6 (VSS), J3.21 (VSS), J3.22 (VSS), J3.39 (VSS), J3.40 (VSS), J4.1 (VSS), J4.2 (VSS), J4.19 (VSS), J4.20 (VSS), J4.37 (VSS), J4.38 (VSS), J5.1, J5.3, J5.5, J5.7, R1.1, R3.2, R7.1, SW1.1, SW2.1, U1.1 (GND), U2.30 (VSS), U2.31 (VREFN), U2.41 (VSSA), U3.3 (VSS), Y1.2, Y1.4
/VUSB: D1.2 (A), J2.A9 (VBUS), J2.B9 (VBUS)
/microcontroller/PIO0_8_I: JP7.2, U2.26 (PIO0_8/XTALIN)
/microcontroller/PIO0_9_I: JP6.2, U2.25 (PIO0_9/XTALOUT)
/microcontroller/VDDA: C12.1, C13.1, C15.1, FB2.1, U2.40 (VDDA), U3.1 (VIN)
/microcontroller/VREFP: C8.1, C9.1, C16.1, U2.32 (VREFP), U3.2 (VOUT)
/microcontroller/XTALIN: C4.1, JP6.1, Y1.1
/microcontroller/XTALOUT: C7.1, JP7.1, Y1.3
unnamed: C17.2, D1.1 (K), FB1.2
unnamed: D2.2 (A), R14.1
unnamed: F1.2, FB1.1
unnamed: J2.A5 (CC1), R1.2
unnamed: J2.B5 (CC2), R7.2
unnamed: R9.2, SW2.2
unnamed: R13.2, SW1.2

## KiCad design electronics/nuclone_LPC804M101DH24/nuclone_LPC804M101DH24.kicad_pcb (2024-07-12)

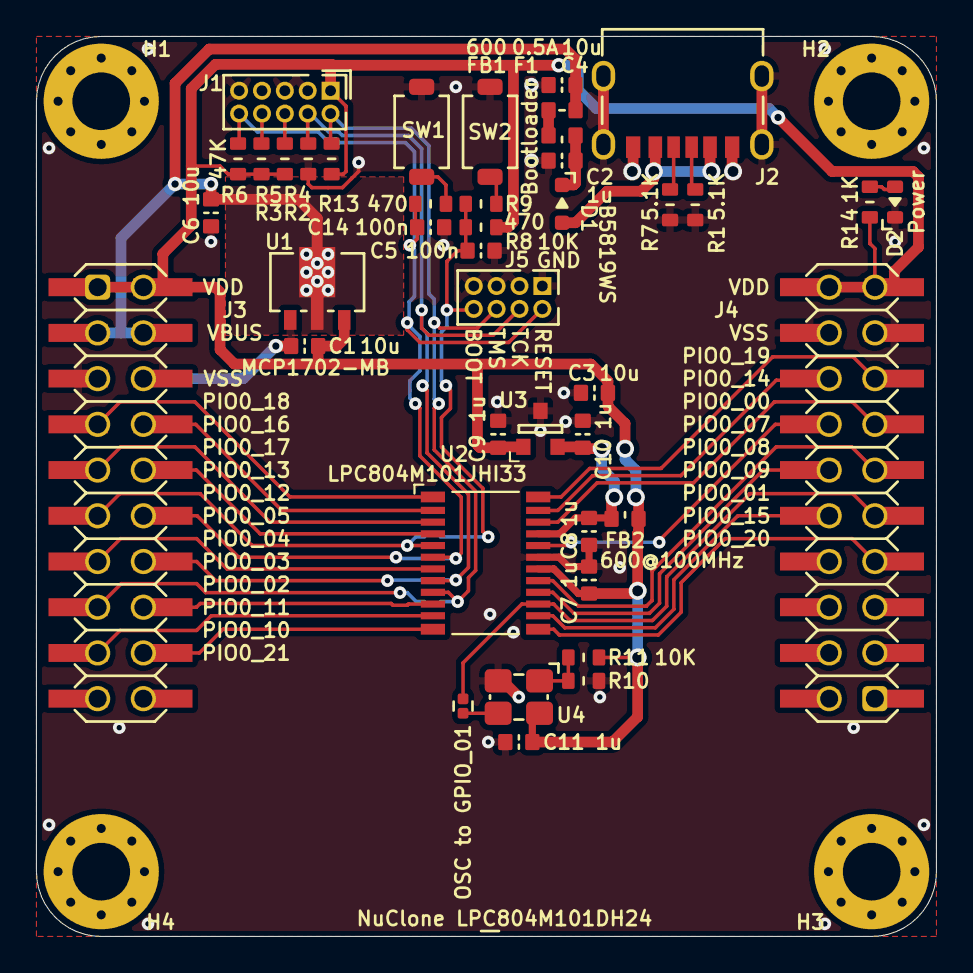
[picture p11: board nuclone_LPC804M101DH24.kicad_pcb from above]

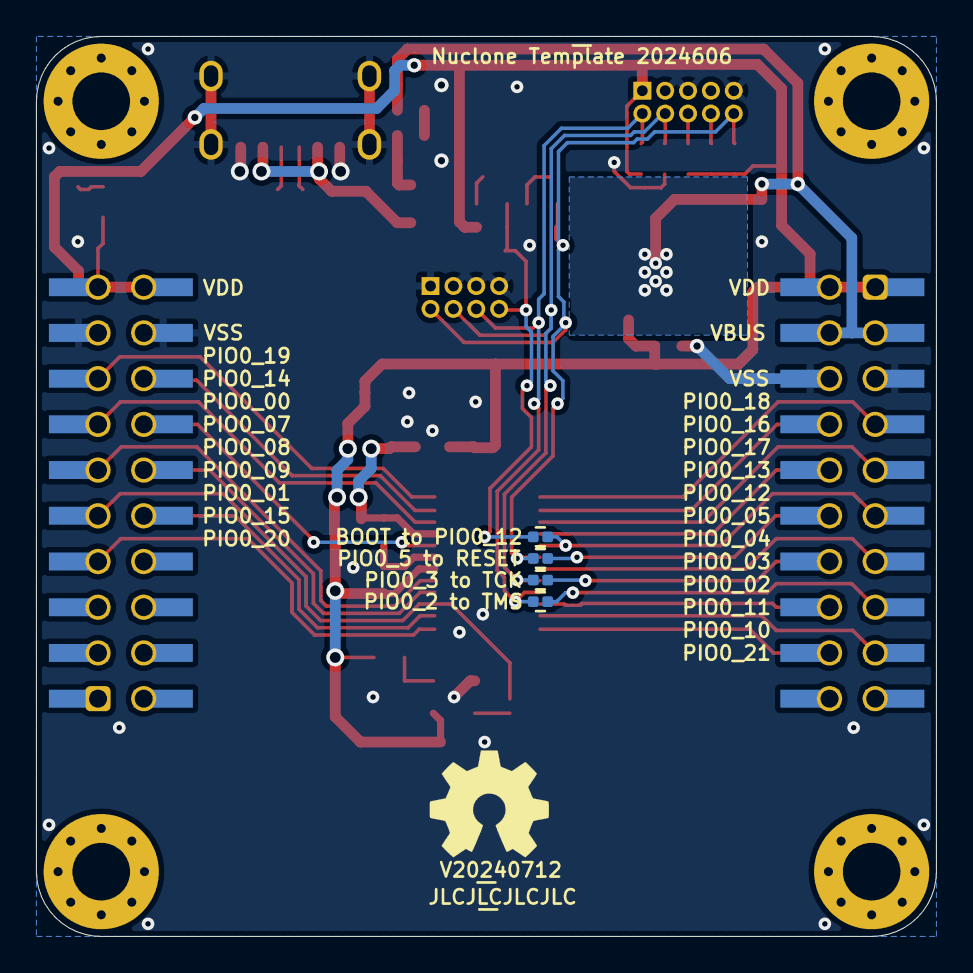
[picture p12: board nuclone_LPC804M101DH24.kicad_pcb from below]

Board: 2 copper layers, 50.0 x 50.0 mm, 55 parts (8 on the bottom side), 41 nets.

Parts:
C1, C3, C4, C6: 10u; C_0603
C2, C7, C8, C9, C10, C11: 1u; C_0603
C5, C14: 100n; C_0603
D1: B5819WS; SOD-323-nexperia-hand
D2: GREEN; LED_0603_hand
F1: 0.5A; F_0603_hand
FB1: 600; L_0603
FB2: 600@100MHz; L_0603
H1, H2, H3, H4: MountingHole; MountingHole_3.2mm_M3_Pad_Via
J1: JTAG_2X05; Header-0127-2X05-H006
J2: TYPE-C-31-M-12; USB-C-HRO-31-M-17_aisler
J3: nuclone_small_left; nuclone_small_left_stacked
J4: nuclone_small_right; nuclone_small_right_stacked
J5: Conn_02x06_Odd_Even; Header-0127-2X04-H006
JP1: PIO0_5 to RESET; solder_jumper_0402_2way_noconn
JP2: PIO0_3 to TCK; solder_jumper_0402_2way_noconn
JP3: PIO0_2 to TMS; solder_jumper_0402_2way_noconn
JP4: BOOT to PIO0_12; solder_jumper_0402_2way_noconn
JP5: OSC to GPIO_01; solder_jumper_0402_2way_noconn
N1: OHWLOGO; OSHW-Symbol_6.7x6mm_SilkScreen
N2: V20240712; Label_Generic
N3: JLCJLCJLCJLC; Label_Generic
N4: NuClone LPC804M101DH24; Label_Generic
N5: Nuclone Template 2024606; Label_Generic
R1, R7: 5.1K; R_0603_hand
R2, R3, R4, R5, R6: 47K; R_0603_hand
R8, R10, R11: 10K; R_0603_hand
R9, R13: 470; R_0603_hand
R14: 1K; R_0603_hand
SW1: RESET; TD-85XU
SW2: Bootloader; TD-85XU
U1: MCP1702-MB; SOT89-NXP
U2: LPC804M101JHI33; SOT355-1-NXP
U3: reference_sot23-3; SOT23-3
U4: TBD; Crystal_3225_4_hand

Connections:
/BOOT: C5.1, J5.8, JP4.1, R8.1, R9.1
/GPIO_00: J3.7 (GPIO_00), U2.1 (PIO0_18)
/GPIO_01: J3.8 (GPIO_01), U2.2 (PIO0_16/ADC_3/ACMP_I4)
/GPIO_02: J3.9 (GPIO_02), U2.3 (PIO0_17/ADC_9)
/GPIO_03: J3.10 (GPIO_03), U2.4 (PIO0_13/ADC_10)
/GPIO_04: J3.11 (GPIO_04), JP4.2, U2.5 (PIO0_12)
/GPIO_05: J3.12 (GPIO_05), JP1.1
/GPIO_06: J3.13 (GPIO_06), U2.7 (PIO0_4/ADC_11/TRSTN)
/GPIO_07: J3.14 (GPIO_07), JP2.1
/GPIO_08: J3.15 (GPIO_08), JP3.1
/GPIO_09: J3.16 (GPIO_09), U2.10 (PIO0_11/ADC_6/WKTCLKIN)
/GPIO_10: J3.17 (GPIO_10), U2.11 (PIO0_10/ADC_7)
/GPIO_11: J3.18 (GPIO_11), U2.12 (PIO0_21/ACMP_I5)
/GPIO_21: J4.7 (GPIO_21), U2.13 (PIO0_20)
/GPIO_22: J4.10 (GPIO_22), U2.14 (PIO0_15/ADC_8)
/GPIO_23: J4.9 (GPIO_23), JP5.2, U2.15 (PIO0_1/ADC_0/ACMP_I2/TDI/CLKIN)
/GPIO_24: J4.12 (GPIO_24), U2.16 (PIO0_9/ADC_4)
/GPIO_25: J4.11 (GPIO_25), U2.17 (PIO0_8/ADC_5)
/GPIO_26: J4.14 (GPIO_26), U2.20 (PIO0_7/ADC_1/ACMPVREF)
/GPIO_27: J4.13 (GPIO_27), U2.22 (PIO0_0/ACMP_I1/TDO)
/GPIO_28: J4.16 (GPIO_28), U2.23 (PIO0_14/ADC_2/ACMP_I3)
/GPIO_29: J4.15 (GPIO_29), U2.24 (PIO0_19/DACOUT)
/RESET: C14.2, J1.10 (nRESET), J5.2, JP1.2, R6.1, R13.1, U2.6 (!RESET/PIO0_5)
/TCK: J1.4 (SWDCLK/TCK), J5.4, JP2.2, R3.1, U2.8 (SWCLK/PIO0_3/TCK)
/TDI: J1.8 (TDI), R5.1
/TDO: J1.6 (SWO/TDO), R4.1
/TMS: J1.2 (SWDIO/TMS), J5.6, JP3.2, R2.1, U2.9 (SWDIO/PIO0_2/TMS)
/VBUS: C4.2, C6.1, F1.1, J3.3 (VBUS), J3.4 (VBUS), U1.2 (Vin)
/VDD: C1.1, C3.1, C7.2, C9.2, C11.2, FB2.1, J1.1 (VCC), J3.1 (VDD), J3.2 (VDD), J4.19 (VDD), J4.20 (VDD), R2.2, R4.2, R5.2, R6.2, R8.2, R11.2, R14.2, U1.3 (Vout), U2.18 (VDD), U3.1 (VIN), U4.4 (VDD)
/VSS: C1.2, C2.1, C3.2, C4.1, C5.2, C6.2, C7.1, C8.1, C9.1, C10.1, C11.1, C14.1, D2.1 (K), J1.3 (GND), J1.5 (GND), J1.9 (GNDDET), J2.A12 (GND), J2.B12 (GND), J2.S (Shield), J3.5 (VSS), J3.6 (VSS), J4.17 (VSS), J4.18 (VSS), J5.1, J5.3, J5.5, J5.7, R1.1, R3.2, R7.1, R10.2, SW1.1, SW2.1, U1.1 (GND), U2.19 (VSS), U3.3 (VSS), U4.2 (GND)
/VUSB: D1.2 (A), J2.A9 (VBUS), J2.B9 (VBUS)
/microcontroller/OSC_EN: R10.1, R11.1, U4.1 (Tri)
/microcontroller/OSC_OUT: JP5.1, U4.3 (OUT)
/microcontroller/VREFP: C8.2, C10.2, FB2.2, U2.21 (VREFP), U3.2 (VOUT)
unnamed: C2.2, D1.1 (K), FB1.2
unnamed: D2.2 (A), R14.1
unnamed: F1.2, FB1.1
unnamed: J2.A5 (CC1), R1.2
unnamed: J2.B5 (CC2), R7.2
unnamed: R9.2, SW2.2
unnamed: R13.2, SW1.2

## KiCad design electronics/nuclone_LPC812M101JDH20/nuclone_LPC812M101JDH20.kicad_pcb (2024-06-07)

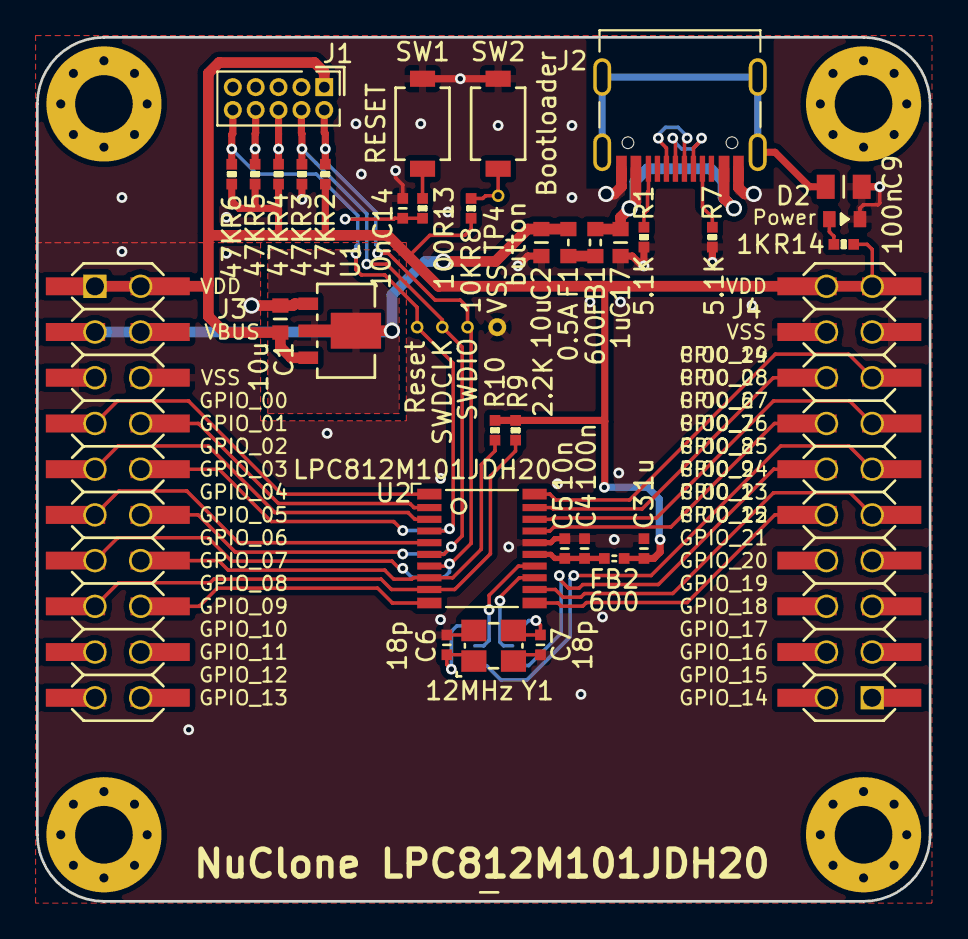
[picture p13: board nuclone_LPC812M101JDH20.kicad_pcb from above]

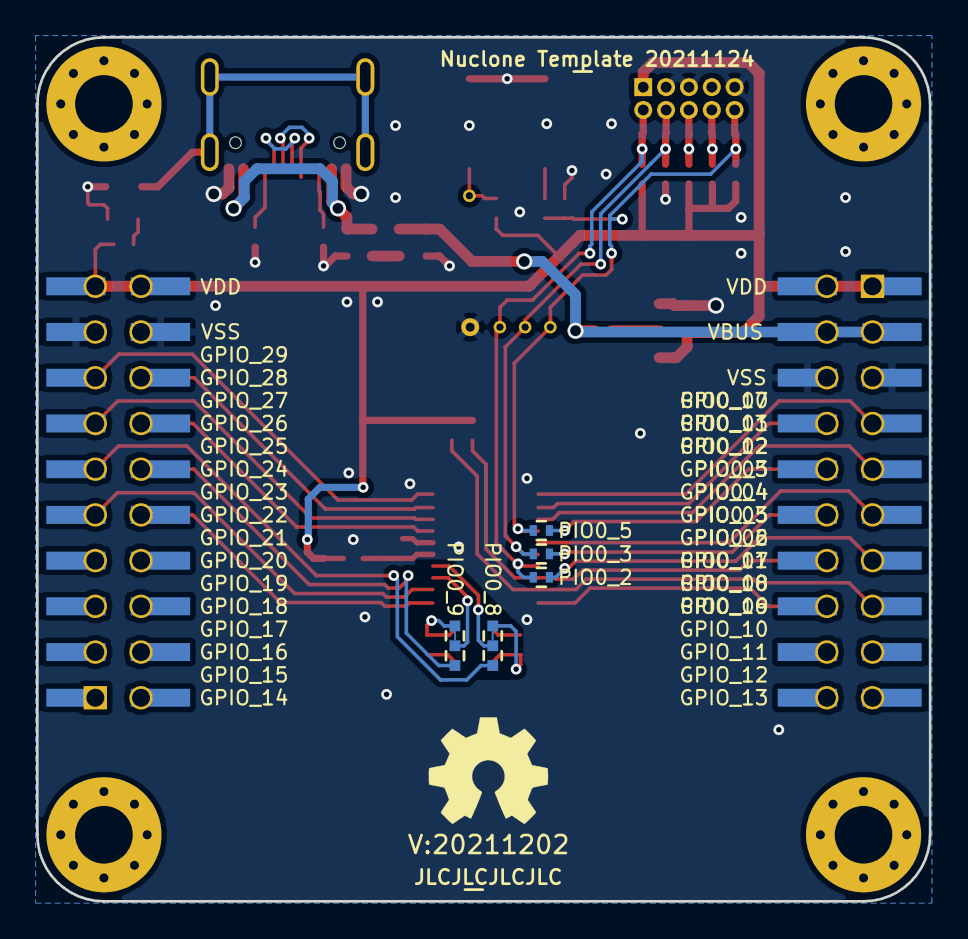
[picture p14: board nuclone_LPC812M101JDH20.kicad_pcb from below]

Board: 2 copper layers, 49.6 x 48.0 mm, 54 parts (9 on the bottom side), 41 nets.

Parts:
C1, C2: 10u; C_0603
C3: 1u; C_0402
C4: 100n; C_0402
C5, C14: 10n; C_0402
C6, C7: 18p; C_0402
C9: 100n; C_0805
C17: 1u; C_0603
D2: GREEN; LED_0603_hand
F1: 0.5A; F_0603_hand
FB1: 600; L_0603
FB2: 600; L_0402
H1, H2, H3, H4: MountingHole; MountingHole_3.2mm_M3_Pad_Via
J1: JTAG_2X05; Header-0127-2X05-H006
J2: TYPE-C-31-M-12; USB-C-HRO-31-M-12
J3: nuclone_small_left; nuclone_small_left_stacked
J4: nuclone_small_right; nuclone_small_right_stacked
JP1: PIO0_5; solder_jumper_2way_noconn
JP2: PIO0_3; solder_jumper_2way_noconn
JP3: PIO0_2; solder_jumper_2way_noconn
JP4: PIO0_8; solder_jumper_3way_12conn
JP5: PIO0_9; solder_jumper_3way_12conn
N1: OHWLOGO; OSHW-Symbol_6.7x6mm_SilkScreen
N2: 20211202; Label_version
N3: JLCJLCJLCJLC; Label_Generic
N4: NuClone LPC812M101JDH20; Label_Generic
N5: Nuclone Template 20211124; Label_Generic
R1, R7: 5.1K; R_0402_hand
R2, R3, R4, R5, R6: 47K; R_0402_hand
R8: 10K; R_0402_hand
R9, R10: 2.2K; R_0402_hand
R13: 100; R_0402_hand
R14: 1K; R_0402_hand
SW1: RESET; TD-85XU
SW2: Bootloader; TD-85XU
TP1: SWDIO; TestPoint_hole_H04R07
TP2: SWDCLK; TestPoint_hole_H04R07
TP3: VSS; TestPoint_hole_H05R10
TP4: button; TestPoint_hole_H04R07
TP5: Reset; TestPoint_hole_H04R07
U1: MCP1702-MB; SOT89-NXP
U2: LPC812M101JDH20; SOT360-NXP
Y1: 12MHz; Crystal_3225_4

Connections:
/Bootloader: R8.1, SW2.2, TP4.1
/GPIO_00: J3.7 (GPIO_00), U2.1 (PIO0_17)
/GPIO_01: J3.8 (GPIO_01), U2.2 (PIO0_13)
/GPIO_02: J3.9 (GPIO_02), U2.3 (PIO0_12)
/GPIO_03: J3.10 (GPIO_03), JP1.1
/GPIO_04: J3.11 (GPIO_04), U2.5 (PIO0_4/WAKEUP/#TRST)
/GPIO_05: J3.12 (GPIO_05), JP2.1
/GPIO_06: J3.13 (GPIO_06), JP3.1
/GPIO_07: J3.14 (GPIO_07), R10.1, U2.8 (PIO0_11/I2C)
/GPIO_08: J3.15 (GPIO_08), R9.1, U2.9 (PIO0_10/I2C)
/GPIO_09: J3.16 (GPIO_09), U2.10 (PIO0_16)
/GPIO_22: J4.10 (GPIO_22), U2.11 (PIO0_15)
/GPIO_23: J4.9 (GPIO_23), U2.12 (PIO0_1/ACMP_I2/CLKIN/TDI)
/GPIO_24: J4.12 (GPIO_24), JP5.3
/GPIO_25: J4.11 (GPIO_25), JP4.3
/GPIO_26: J4.14 (GPIO_26), U2.17 (PIO0_7)
/GPIO_27: J4.13 (GPIO_27), U2.18 (PIO0_6/VDDCMP)
/GPIO_28: J4.16 (GPIO_28), U2.19 (PIO0_0/ACMP_I1/TDO)
/GPIO_29: J4.15 (GPIO_29), U2.20 (PIO0_14)
/RESET: C14.2, J1.10 (nRESET), JP1.2, R6.1, R13.1, TP5.1, U2.4 (#RESET/PIO0_5)
/TCK: J1.4 (SWDCLK/TCK), JP2.2, R3.1, TP2.1, U2.6 (SWCLK/PIO0_3/TCK)
/TDI: J1.8 (TDI), R5.1
/TDO: J1.6 (SWO/TDO), R4.1
/TMS: J1.2 (SWDIO/TMS), JP3.2, R2.1, TP1.1, U2.7 (SWDIO/PIO0_2/TMS)
/VBUS: C2.2, F1.1, J3.3 (VBUS), J3.4 (VBUS), U1.2 (Vin)
/VDD: C1.1, C3.1, FB2.2, J1.1 (VCC), J3.1 (VDD), J3.2 (VDD), J4.19 (VDD), J4.20 (VDD), R2.2, R4.2, R5.2, R6.2, R8.2, R9.2, R10.2, R14.2, U1.3 (Vout)
/VSS: C1.2, C2.1, C3.2, C4.2, C5.2, C6.2, C7.2, C9.1, C14.1, C17.1, D2.1 (K), J1.3 (GND), J1.5 (GND), J1.9 (GNDDET), J2.A1B12 (GND), J2.B1A12 (GND), J3.5 (VSS), J3.6 (VSS), J4.17 (VSS), J4.18 (VSS), R1.1, R3.2, R7.1, SW1.1, SW2.1, TP3.1, U1.1 (GND), U2.16 (VSS), Y1.2, Y1.4
/microcontroller/XTALIN: JP4.2, U2.14 (PIO0_8/XTALIN)
/microcontroller/XTALOUT: JP5.2, U2.13 (PIO0_9/XTALOUT)
unnamed: C4.1, C5.1, FB2.1, U2.15 (VDD)
unnamed: C6.1, JP4.1, Y1.1
unnamed: C7.1, JP5.1, Y1.3
unnamed: C9.2, J2.S (Shield)
unnamed: C17.2, FB1.2, J2.A4B9 (VBUS), J2.B4A9 (VBUS)
unnamed: D2.2 (A), R14.1
unnamed: F1.2, FB1.1
unnamed: J2.A5 (CC1), R7.2
unnamed: J2.A6 (DP1), J2.B6 (DP2)
unnamed: J2.A7 (DN1), J2.B7 (DN2)
unnamed: J2.B5 (CC2), R1.2
unnamed: R13.2, SW1.2

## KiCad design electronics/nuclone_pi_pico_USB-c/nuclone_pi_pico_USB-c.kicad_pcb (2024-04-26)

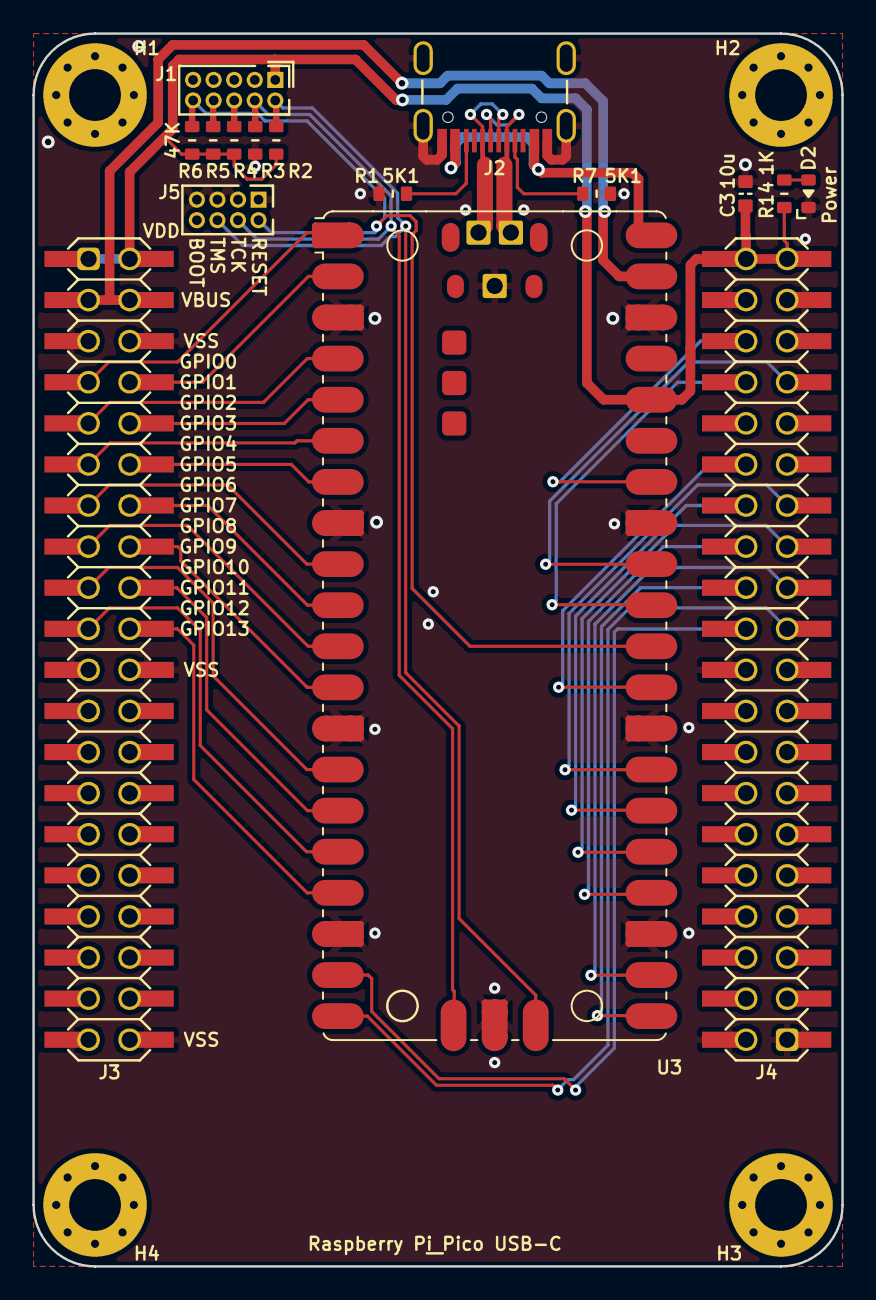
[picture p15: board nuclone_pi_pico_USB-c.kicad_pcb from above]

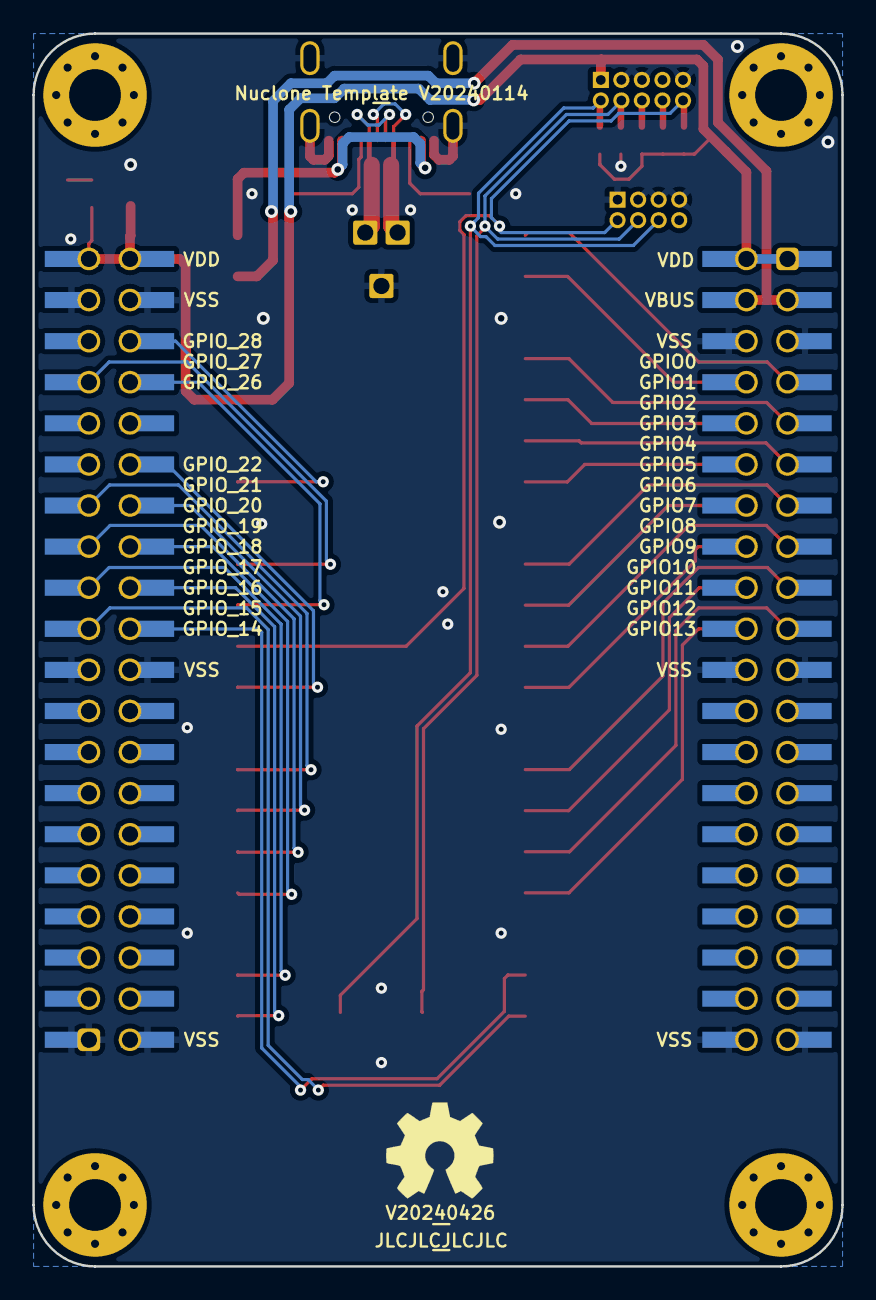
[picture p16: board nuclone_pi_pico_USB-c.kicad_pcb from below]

Board: 2 copper layers, 50.0 x 76.2 mm, 25 parts (4 on the bottom side), 40 nets.

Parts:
C3: 10u; C_0603
D2: GREEN; LED_0603_hand
H1, H2, H3, H4: MountingHole; MountingHole_3.2mm_M3_Pad_Via
J1: JTAG_2X05; Header-0127-2X05-H006
J2: USB-C_PD_USB; USB-C-HRO-31-M-12_aisler
J3: nuclone_medium_left; nuclone_medium_left_stacked
J4: nuclone_medium_right; nuclone_medium_right_stacked
J5: Conn_02x06_Odd_Even; Header-0127-2X04-H006
N1: OHWLOGO; OSHW-Symbol_6.7x6mm_SilkScreen
N2: V20240426; Label_Generic
N3: JLCJLCJLCJLC; Label_Generic
N4: Raspberry Pi Pico USB-C; Label_Generic
N5: Nuclone Template V20240114; Label_Generic
R1, R7: 5K1; R_0603_hand
R2, R3, R4, R5, R6: 47K; R_0603_hand
R14: 1K; R_0603_hand
U3: RaspberryPiPico; RaspberryPi_Pico_Original_SMD_nokeepout_USB_TP_TH

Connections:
/GPIO_00: J3.7 (GPIO_00), U3.1 (GP0)
/GPIO_01: J3.8 (GPIO_01), U3.2 (GP1)
/GPIO_02: J3.9 (GPIO_02), U3.4 (GP2)
/GPIO_03: J3.10 (GPIO_03), U3.5 (GP3)
/GPIO_04: J3.11 (GPIO_04), U3.6 (GP4)
/GPIO_05: J3.12 (GPIO_05), U3.7 (GP5)
/GPIO_06: J3.13 (GPIO_06), U3.9 (GP6)
/GPIO_07: J3.14 (GPIO_07), U3.10 (GP7)
/GPIO_08: J3.15 (GPIO_08), U3.11 (GP8)
/GPIO_09: J3.16 (GPIO_09), U3.12 (GP9)
/GPIO_10: J3.17 (GPIO_10), U3.14 (GP10)
/GPIO_11: J3.18 (GPIO_11), U3.15 (GP11)
/GPIO_12: J3.19 (GPIO_12), U3.16 (GP12)
/GPIO_13: J3.20 (GPIO_13), U3.17 (GP13)
/GPIO_46: J4.22 (GPIO_46), U3.19 (GP14)
/GPIO_47: J4.21 (GPIO_47), U3.20 (GP15)
/GPIO_48: J4.24 (GPIO_48), U3.21 (GP16)
/GPIO_49: J4.23 (GPIO_49), U3.22 (GP17)
/GPIO_50: J4.26 (GPIO_50), U3.24 (GP18)
/GPIO_51: J4.25 (GPIO_51), U3.25 (GP19)
/GPIO_52: J4.28 (GPIO_52), U3.26 (GP20)
/GPIO_53: J4.27 (GPIO_53), U3.27 (GP21)
/GPIO_54: J4.30 (GPIO_54), U3.29 (GP22)
/GPIO_58: J4.34 (GPIO_58), U3.31 (GP26_A0)
/GPIO_59: J4.33 (GPIO_59), U3.32 (GP27_A1)
/GPIO_60: J4.36 (GPIO_60), U3.34 (GP28_A2)
/RESET: J1.10 (nRESET), J5.2, R6.1, U3.30 (RUN)
/TCK: J1.4 (SWDCLK/TCK), J5.4, R3.1, U3.D1 (SWCLK)
/TDI: J1.8 (TDI), R5.1
/TDO: J1.6 (SWO/TDO), R4.1
/TMS: J1.2 (SWDIO/TMS), J5.6, R2.1, U3.D3 (SWDIO)
/USB_D+: J2.A6 (DP1), J2.B6 (DP2), U3.TP3 (USB_DP)
/USB_D-: J2.A7 (DN1), J2.B7 (DN2), U3.TP2 (USB_DM)
/VBUS: J2.A4B9 (VBUS), J2.B4A9 (VBUS), U3.40 (VBUS)
/VDD: C3.1, J1.1 (VCC), J3.1 (VDD), J3.2 (VDD), J4.39 (VDD), J4.40 (VDD), R2.2, R4.2, R5.2, R6.2, R14.2, U3.36 (3V3)
/VSS: C3.2, D2.1 (K), J1.3 (GND), J1.5 (GND), J1.9 (GNDDET), J2.A1B12 (GND), J2.B1A12 (GND), J2.S (Shield), J3.5 (VSS), J3.6 (VSS), J3.21 (VSS), J3.22 (VSS), J3.39 (VSS), J3.40 (VSS), J4.1 (VSS), J4.2 (VSS), J4.19 (VSS), J4.20 (VSS), J4.37 (VSS), J4.38 (VSS), J5.1, J5.3, J5.5, J5.7, R1.1, R3.2, R7.1, U3.3 (GND), U3.8 (GND), U3.13 (GND), U3.18 (GND), U3.23 (GND), U3.28 (GND), U3.33 (AGND), U3.38 (GND), U3.D2 (GND), U3.TP1 (GND)
/VSYS: J3.3 (VBUS), J3.4 (VBUS), U3.39 (VSYS)
unnamed: D2.2 (A), R14.1
unnamed: J2.A5 (CC1), R7.2
unnamed: J2.B5 (CC2), R1.2

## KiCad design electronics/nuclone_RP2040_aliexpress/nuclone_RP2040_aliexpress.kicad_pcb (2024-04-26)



Board: 2 copper layers, 50.0 x 76.2 mm, 22 parts (4 on the bottom side), 39 nets.

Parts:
C3: 10u; C_0603
D2: GREEN; LED_0603_hand
H1, H2, H3, H4: MountingHole; MountingHole_3.2mm_M3_Pad_Via
J1: JTAG_2X05; Header-0127-2X05-H006
J3: nuclone_medium_left; nuclone_medium_left_stacked
J4: nuclone_medium_right; nuclone_medium_right_stacked
J5: Conn_02x06_Odd_Even; Header-0127-2X04-H006
N1: OHWLOGO; OSHW-Symbol_6.7x6mm_SilkScreen
N2: V20240426; Label_Generic
N3: JLCJLCJLCJLC; Label_Generic
N4: NuClone RP2040 aliexpress; Label_Generic
N5: Nuclone Template V20240218; Label_Generic
R2, R3, R4, R5, R6: 47K; R_0603_hand
R14: 1K; R_0603_hand
U1: RP2040_aliexpress; module_rp2040_aliexpress

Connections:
/GPIO_00: J3.7 (GPIO_00), U1.1 (GP0)
/GPIO_01: J3.8 (GPIO_01), U1.2 (GP1)
/GPIO_02: J3.9 (GPIO_02), U1.3 (GP2)
/GPIO_03: J3.10 (GPIO_03), U1.4 (GP3)
/GPIO_04: J3.11 (GPIO_04), U1.5 (GP4)
/GPIO_05: J3.12 (GPIO_05), U1.7 (GP5)
/GPIO_06: J3.13 (GPIO_06), U1.8 (GP6)
/GPIO_07: J3.14 (GPIO_07), U1.9 (GP7)
/GPIO_08: J3.15 (GPIO_08), U1.10 (GP8)
/GPIO_09: J3.16 (GPIO_09), U1.11 (GP9)
/GPIO_10: J3.17 (GPIO_10), U1.12 (GP10)
/GPIO_11: J3.18 (GPIO_11), U1.13 (GP11)
/GPIO_12: J3.19 (GPIO_12), U1.14 (GP12)
/GPIO_13: J3.20 (GPIO_13), U1.16 (GP13)
/GPIO_46: J4.22 (GPIO_46), U1.17 (GP14)
/GPIO_47: J4.21 (GPIO_47), U1.18 (GP15)
/GPIO_48: J4.24 (GPIO_48), U1.19 (GP16)
/GPIO_49: J4.23 (GPIO_49), U1.20 (GP17)
/GPIO_50: J4.26 (GPIO_50), U1.21 (GP18)
/GPIO_51: J4.25 (GPIO_51), U1.22 (GP19)
/GPIO_52: J4.28 (GPIO_52), U1.23 (GP20)
/GPIO_53: J4.27 (GPIO_53), U1.24 (GP21)
/GPIO_54: J4.30 (GPIO_54), U1.25 (GP22)
/GPIO_55: J4.29 (GPIO_55), U1.26 (GP23)
/GPIO_56: J4.32 (GPIO_56), U1.27 (GP24)
/GPIO_57: J4.31 (GPIO_57), U1.28 (GP25)
/GPIO_58: J4.34 (GPIO_58), U1.30 (GP26_A0)
/GPIO_59: J4.33 (GPIO_59), U1.31 (GP27_A1)
/GPIO_60: J4.36 (GPIO_60), U1.32 (GP28_A2)
/GPIO_61: J4.35 (GPIO_61), U1.33 (GP29_A3)
/RESET: J1.10 (nRESET), J5.2, R6.1, U1.34 (RUN)
/TCK: J1.4 (SWDCLK/TCK), J5.4, R3.1, U1.43 (SWCLK)
/TDI: J1.8 (TDI), R5.1
/TDO: J1.6 (SWO/TDO), R4.1
/TMS: J1.2 (SWDIO/TMS), J5.6, R2.1, U1.44 (SWDIO)
/VBUS: J3.3 (VBUS), J3.4 (VBUS), U1.39 (VIN)
/VDD: C3.1, J1.1 (VCC), J3.1 (VDD), J3.2 (VDD), J4.39 (VDD), J4.40 (VDD), R2.2, R4.2, R5.2, R6.2, R14.2, U1.36 (3V3), U1.41 (3V3)
/VSS: C3.2, D2.1 (K), J1.3 (GND), J1.5 (GND), J1.9 (GNDDET), J3.5 (VSS), J3.6 (VSS), J3.21 (VSS), J3.22 (VSS), J3.39 (VSS), J3.40 (VSS), J4.1 (VSS), J4.2 (VSS), J4.19 (VSS), J4.20 (VSS), J4.37 (VSS), J4.38 (VSS), J5.1, J5.3, J5.5, J5.7, R3.2, U1.6 (GND), U1.15 (GND), U1.29 (AGND), U1.35 (GND), U1.38 (GND), U1.42 (GND)
unnamed: D2.2 (A), R14.1

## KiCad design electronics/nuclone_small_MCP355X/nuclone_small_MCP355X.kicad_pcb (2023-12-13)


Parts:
C1: 10n; C_0603
C2, C3: 2.2n; C_0603
C4: 10u; C_0603
C5, C6, C7, C8: 1u; C_0603
D1: A7 LCSC; SOD-123F-hand
D2, D3, D4, D5: SD05; SOD-323-nexperia-hand
D6: LED; LED_0603_hand
F1: 0.5A; F_0603_hand
FB1: 600; L_0603
H1, H2, H3, H4: MountingHole; MountingHole_3.2mm_M3_Pad_Via
J1, J2, J7, J8: Conn_01x04; Header-0254-1X04-H010
J3: nuclone_small_left; nuclone_small_left_stacked
J4: nuclone_small_right; nuclone_small_right_stacked
J6: DevBoardUartInput; JST_PH_B4B-PH-K_1x04_P2.00mm_Vertical
J9, J10, J11, J12: Conn_01x04; Header-0254-1X02-H010
J13: Conn_01x04; JST_XH_B4B-XH-A_1x04_P2.50mm_Vertical
J15: Conn_02x03_Odd_Even; Header-0254-2X03-H010
J16: Conn_02x04_Odd_Even; Header-0254-2X04-H010
N1: OHWLOGO; OSHW-Symbol_6.7x6mm_SilkScreen
N2: V20231213; Label_Generic
N3: JLCJLCJLCJLC; Label_Generic
R1, R2, R12: 1K; R_0603_hand
R3: 10; R_0603_hand
R4, R5, R6, R7, R8, R9, R10, R11: 1K; R_0805+0603
TP1: VDD1; TestPoint_hole_H05R10_2side
TP2: VBUS; TestPoint_hole_H05R10_2side
TP3, TP19: VSS; TestPoint_hole_H05R10_2side
TP4: P00; TestPoint_hole_H05R10_2side
TP5: P01; TestPoint_hole_H05R10_2side
TP6: P02; TestPoint_hole_H05R10_2side
TP7: P03; TestPoint_hole_H05R10_2side
TP8: P04; TestPoint_hole_H05R10_2side
TP9: P05; TestPoint_hole_H05R10_2side
TP10: P06; TestPoint_hole_H05R10_2side
TP11: P07; TestPoint_hole_H05R10_2side
TP12: P08; TestPoint_hole_H05R10_2side
TP13: P09; TestPoint_hole_H05R10_2side
TP14: P10; TestPoint_hole_H05R10_2side
TP15: P11; TestPoint_hole_H05R10_2side
TP16: P12; TestPoint_hole_H05R10_2side
TP17: P13; TestPoint_hole_H05R10_2side
TP18: VDD2; TestPoint_hole_H05R10_2side
TP20: P29; TestPoint_hole_H05R10_2side
TP21: P28; TestPoint_hole_H05R10_2side
TP22: P27; TestPoint_hole_H05R10_2side
TP23: P26; TestPoint_hole_H05R10_2side
TP24: P25; TestPoint_hole_H05R10_2side
TP25: P24; TestPoint_hole_H05R10_2side
TP26: P23; TestPoint_hole_H05R10_2side
TP27: P22; TestPoint_hole_H05R10_2side
TP28: P21; TestPoint_hole_H05R10_2side
TP29: P20; TestPoint_hole_H05R10_2side
TP30: P19; TestPoint_hole_H05R10_2side
TP31: P18; TestPoint_hole_H05R10_2side
TP32: P17; TestPoint_hole_H05R10_2side
TP33: P16; TestPoint_hole_H05R10_2side
TP34: P15; TestPoint_hole_H05R10_2side
TP35: P14; TestPoint_hole_H05R10_2side
U1: MCP355X; SOIC-8
U2: reference_sot23-3; SOT23-3

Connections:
/CS: J15.1, U1.7 (/CS)
/DIV1: J1.1, J1.2, R4.1, R5.1
/DIV2: J1.3, J1.4, R6.1, R7.1
/DIV3: J8.1, J8.2, R8.1, R9.1
/DIV4: J8.3, J8.4, R10.1, R11.1
/GPIO_00: J3.7 (GPIO_00), TP4.1
/GPIO_01: J3.8 (GPIO_01), TP5.1
/GPIO_02: J3.9 (GPIO_02), TP6.1
/GPIO_03: J3.10 (GPIO_03), TP7.1
/GPIO_04: J3.11 (GPIO_04), TP8.1
/GPIO_05: J3.12 (GPIO_05), TP9.1
/GPIO_06: J3.13 (GPIO_06), TP10.1
/GPIO_07: J3.14 (GPIO_07), TP11.1
/GPIO_08: J3.15 (GPIO_08), TP12.1
/GPIO_09: J3.16 (GPIO_09), TP13.1
/GPIO_10: J3.17 (GPIO_10), TP14.1
/GPIO_11: J3.18 (GPIO_11), TP15.1
/GPIO_12: J3.19 (GPIO_12), TP16.1
/GPIO_13: J3.20 (GPIO_13), TP17.1
/GPIO_14: J4.2 (GPIO_14), TP35.1
/GPIO_15: J4.1 (GPIO_15), TP34.1
/GPIO_16: J4.4 (GPIO_16), TP33.1
/GPIO_17: J4.3 (GPIO_17), TP32.1
/GPIO_18: J4.6 (GPIO_18), TP31.1
/GPIO_19: J4.5 (GPIO_19), TP30.1
/GPIO_20: J4.8 (GPIO_20), TP29.1
/GPIO_21: J4.7 (GPIO_21), TP28.1
/GPIO_22: J4.10 (GPIO_22), TP27.1
/GPIO_23: J4.9 (GPIO_23), TP26.1
/GPIO_24: J4.12 (GPIO_24), TP25.1
/GPIO_25: J4.11 (GPIO_25), TP24.1
/GPIO_26: J4.14 (GPIO_26), TP23.1
/GPIO_27: J4.13 (GPIO_27), TP22.1
/GPIO_28: J4.16 (GPIO_28), TP21.1
/GPIO_29: J4.15 (GPIO_29), TP20.1
/Input1: D2.1 (A1), J9.1, J9.2, J13.1
/Input2: D3.1 (A1), J10.1, J10.2, J13.2
/Input3: D4.1 (A1), J11.1, J11.2, J13.3
/Input4: D5.1 (A1), J12.1, J12.2, J13.4
/RXD: J6.3 (RX), J16.7
/SCK: J15.5, U1.5 (SCK)
/SDO: J15.3, U1.6 (SDO/RDY)
/TXD: J6.4 (TX), J16.5
/VBUS: C4.1, FB1.1, J3.3 (VBUS), J3.4 (VBUS), R12.2, TP2.1
/VDD1: J3.1 (VDD), J3.2 (VDD), TP1.1
/VDD2: C7.1, J4.19 (VDD), J4.20 (VDD), R3.2, TP18.1, U2.1 (VIN)
/VIN: D1.2 (A), J6.2 (VBUS)
/VREF: C6.2, C8.1, R5.2, R7.2, R9.2, R11.2, U1.1 (Vref), U2.2 (VOUT)
/VSS: C2.1, C3.1, C4.2, C5.1, C6.1, C7.2, C8.2, D2.2 (A2), D3.2 (A2), D4.2 (A2), D5.2 (A2), D6.1 (K), J3.5 (VSS), J3.6 (VSS), J4.17 (VSS), J4.18 (VSS), J6.1 (GND), J15.2, J15.4, J15.6, J16.2, J16.4, J16.6, J16.8, R4.2, R6.2, R8.2, R10.2, TP3.1, TP19.1, U1.4 (Vss), U2.3 (VSS)
/V_IN+: J2.1, J2.2, J2.3, J2.4, R1.1
/V_IN-: C1.1, J7.1, J7.2, J7.3, J7.4, R2.1
unnamed: D1.1 (K), F1.2
unnamed: D6.2 (A), R12.1
unnamed: F1.1, FB1.2
unnamed: C5.2, R3.1, U1.8 (Vdd)
unnamed: C1.2, C3.2, R1.2, U1.2 (Vin+)
unnamed: C2.2, R2.2, U1.3 (Vin-)

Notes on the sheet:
Labels and mounting
Voltage reference
Input connection
Reference
TODO
Breadboard
GPIO pinouts
ADC
Nuclone connections
Dividers
UART input



Board: 2 copper layers, 50.0 x 50.0 mm, 86 parts (3 on the bottom side), 57 nets.

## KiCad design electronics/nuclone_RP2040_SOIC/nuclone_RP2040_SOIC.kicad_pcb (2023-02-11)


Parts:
C1, C2: 10u; C_0603
C4: 1u; C_0402
C9: 100n; C_0805
C14: 10n; C_0402
C17: 1u; C_0603
D2: GREEN; LED_0603_hand
F1: 0.5A; F_0603_hand
FB1: 600; L_0603
H1, H2, H3, H4: MountingHole; MountingHole_3.2mm_M3_Pad_Via
J1: JTAG_2X05; Header-0127-2X05-H006
J2: TYPE-C-31-M-12; USB-C-HRO-31-M-12
J3: nuclone_small_left; nuclone_small_left_stacked
J4: nuclone_small_right; nuclone_small_right_stacked
N1: OHWLOGO; OSHW-Symbol_6.7x6mm_SilkScreen
N2: V20230211; Label_Generic
N3: JLCJLCJLCJLC; Label_Generic
N4: NuClone RP2040 SOIC; Label_Generic
N5: Nuclone Template 20220513; Label_Generic
R1, R7: 5.1K; R_0402_hand
R2, R3, R4, R5, R6: 47K; R_0402_hand
R8: 10K; R_0402_hand
R13: 100; R_0402_hand
R14: 1K; R_0402_hand
SW1: RESET; TD-85XU
SW2: Bootloader; TD-85XU
U1: MCP1702-MB; SOT89-NXP
U2: TPESD0504C6; SOT363-ONsemi

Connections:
/BOOTLOADER: R8.1, SW2.2; also elsewhere on the board
/DN: J2.A7 (DN1), J2.B7 (DN2), U2.6 (IO_4); also elsewhere on the board
/DP: J2.A6 (DP1), J2.B6 (DP2), U2.1 (IO_1); also elsewhere on the board
/GPIO_00: J3.7 (GPIO_00); also elsewhere on the board
/GPIO_01: J3.8 (GPIO_01); also elsewhere on the board
/GPIO_02: J3.9 (GPIO_02); also elsewhere on the board
/GPIO_03: J3.10 (GPIO_03); also elsewhere on the board
/GPIO_04: J3.11 (GPIO_04); also elsewhere on the board
/GPIO_05: J3.12 (GPIO_05); also elsewhere on the board
/GPIO_06: J3.13 (GPIO_06); also elsewhere on the board
/GPIO_07: J3.14 (GPIO_07); also elsewhere on the board
/GPIO_08: J3.15 (GPIO_08); also elsewhere on the board
/GPIO_09: J3.16 (GPIO_09); also elsewhere on the board
/GPIO_10: J3.17 (GPIO_10); also elsewhere on the board
/GPIO_11: J3.18 (GPIO_11); also elsewhere on the board
/GPIO_12: J3.19 (GPIO_12); also elsewhere on the board
/GPIO_13: J3.20 (GPIO_13); also elsewhere on the board
/GPIO_14: J4.2 (GPIO_14); also elsewhere on the board
/GPIO_15: J4.1 (GPIO_15); also elsewhere on the board
/GPIO_16: J4.4 (GPIO_16); also elsewhere on the board
/GPIO_17: J4.3 (GPIO_17); also elsewhere on the board
/GPIO_18: J4.6 (GPIO_18); also elsewhere on the board
/GPIO_19: J4.5 (GPIO_19); also elsewhere on the board
/GPIO_20: J4.8 (GPIO_20); also elsewhere on the board
/GPIO_21: J4.7 (GPIO_21); also elsewhere on the board
/GPIO_22: J4.10 (GPIO_22); also elsewhere on the board
/GPIO_23: J4.9 (GPIO_23); also elsewhere on the board
/GPIO_24: J4.12 (GPIO_24); also elsewhere on the board
/GPIO_25: J4.11 (GPIO_25); also elsewhere on the board
/GPIO_26: J4.14 (GPIO_26); also elsewhere on the board
/GPIO_27: J4.13 (GPIO_27); also elsewhere on the board
/GPIO_28: J4.16 (GPIO_28); also elsewhere on the board
/GPIO_29: J4.15 (GPIO_29); also elsewhere on the board
/RESET: C14.2, J1.10 (nRESET), R6.1, R13.1; also elsewhere on the board
/TCK: J1.4 (SWDCLK/TCK), R3.1; also elsewhere on the board
/TDI: J1.8 (TDI), R5.1
/TDO: J1.6 (SWO/TDO), R4.1
/TMS: J1.2 (SWDIO/TMS), R2.1; also elsewhere on the board
/VBUS: C2.2, F1.1, J3.3 (VBUS), J3.4 (VBUS), U1.2 (Vin)
/VDD: C1.1, J1.1 (VCC), J3.1 (VDD), J3.2 (VDD), J4.19 (VDD), J4.20 (VDD), R2.2, R3.2, R4.2, R5.2, R6.2, R8.2, R14.2, U1.3 (Vout); also elsewhere on the board
/VSS: C1.2, C2.1, C4.2, C9.1, C14.1, C17.1, D2.1 (K), J1.3 (GND), J1.5 (GND), J1.9 (GNDDET), J2.A1B12 (GND), J2.B1A12 (GND), J3.5 (VSS), J3.6 (VSS), J4.17 (VSS), J4.18 (VSS), R1.1, R7.1, SW1.1, SW2.1, U1.1 (GND), U2.2 (VSS); also elsewhere on the board
/VUSB: C4.1, C17.2, FB1.2, J2.A4B9 (VBUS), J2.B4A9 (VBUS), U2.5 (VDD)
unnamed: C9.2, J2.S (Shield)
unnamed: D2.2 (A), R14.1
unnamed: F1.2, FB1.1
unnamed: J2.A5 (CC1), R7.2
unnamed: J2.B5 (CC2), R1.2
unnamed: R13.2, SW1.2

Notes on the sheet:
JTAG
Power regulator
TODO
Additional circuits
Nuclone connections
Labels and mounting
Power input


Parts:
C5, C6, C7, C8, C10, C13, C15, C18, C19, C20, C21, C22: 1u; C_0402
C11, C12: 22p; C_0402
C23: 10u; C_0603
FB2: 600; L_0402
J5: Conn_02x06_Odd_Even; Header-0127-2X10-H006
R9: TBD; R_0402_hand
R10: DNF; R_0402_hand
R11: 1K; R_0402_hand
R12, R15: 27; R_0402_hand
U3: rp2040; QFN56_7by7mm_RaspberryPi
U4: generic QSPI flash; SOIC-8_dual_wide
Y1: 12MHz; Crystal_2520_4

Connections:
/BOOTLOADER: J5.2, R11.1; also elsewhere on the board
/DN: R15.1; also elsewhere on the board
/DP: R12.1; also elsewhere on the board
/GPIO_00: U3.2 (GPIO0); also elsewhere on the board
/GPIO_01: U3.3 (GPIO1); also elsewhere on the board
/GPIO_02: U3.4 (GPIO2); also elsewhere on the board
/GPIO_03: U3.5 (GPIO3); also elsewhere on the board
/GPIO_04: U3.6 (GPIO4); also elsewhere on the board
/GPIO_05: U3.7 (GPIO5); also elsewhere on the board
/GPIO_06: U3.8 (GPIO6); also elsewhere on the board
/GPIO_07: U3.9 (GPIO7); also elsewhere on the board
/GPIO_08: U3.11 (GPIO8); also elsewhere on the board
/GPIO_09: U3.12 (GPIO9); also elsewhere on the board
/GPIO_10: U3.13 (GPIO10); also elsewhere on the board
/GPIO_11: U3.14 (GPIO11); also elsewhere on the board
/GPIO_12: U3.15 (GPIO12); also elsewhere on the board
/GPIO_13: U3.16 (GPIO13); also elsewhere on the board
/GPIO_14: U3.17 (GPIO14); also elsewhere on the board
/GPIO_15: U3.18 (GPIO15); also elsewhere on the board
/GPIO_16: U3.27 (GPIO16); also elsewhere on the board
/GPIO_17: U3.28 (GPIO17); also elsewhere on the board
/GPIO_18: U3.29 (GPIO18); also elsewhere on the board
/GPIO_19: U3.30 (GPIO19); also elsewhere on the board
/GPIO_20: U3.31 (GPIO20); also elsewhere on the board
/GPIO_21: U3.32 (GPIO21); also elsewhere on the board
/GPIO_22: U3.34 (GPIO22); also elsewhere on the board
/GPIO_23: U3.35 (GPIO23); also elsewhere on the board
/GPIO_24: U3.36 (GPIO24); also elsewhere on the board
/GPIO_25: U3.37 (GPIO25); also elsewhere on the board
/GPIO_26: U3.38 (GPIO26/ADC0); also elsewhere on the board
/GPIO_27: U3.39 (GPIO27/ADC1); also elsewhere on the board
/GPIO_28: U3.40 (GPIO28/ADC2); also elsewhere on the board
/GPIO_29: U3.41 (GPIO29/ADC3); also elsewhere on the board
/RESET: J5.8, U3.26 (RUN); also elsewhere on the board
/TCK: J5.6, U3.24 (SWCLK); also elsewhere on the board
/TMS: J5.4, U3.25 (SWDIO); also elsewhere on the board
/VDD: C5.2, C6.2, C7.2, C8.2, C10.2, C13.2, C20.2, C22.2, C23.2, FB2.1, R10.1, U3.1 (IOVDD), U3.10 (IOVDD), U3.22 (IOVDD), U3.33 (IOVDD), U3.42 (IOVDD), U3.44 (VREG_IN), U3.48 (USB_VDD), U3.49 (IOVDD), U4.8 (VCC); also elsewhere on the board
/VSS: C5.1, C6.1, C7.1, C8.1, C10.1, C11.1, C12.1, C13.1, C15.1, C18.1, C19.1, C20.1, C21.1, C22.1, C23.1, J5.1, J5.3, J5.5, J5.7, J5.9, J5.11, J5.13, J5.15, J5.17, J5.19, U3.19 (TESTEN), U3.57 (GND), U4.4 (GND), Y1.2, Y1.4; also elsewhere on the board
/microcontroller/1.1V: C15.2, C18.2, C21.2, U3.23 (DVDD), U3.45 (VREG_OUT), U3.50 (DVDD)
/microcontroller/AVDD: C19.2, FB2.2, U3.43 (ADC_AVDD)
/microcontroller/QSPI_SCLK: J5.18, U3.52 (QSPI_SCLK), U4.6 (SCLK)
/microcontroller/QSPI_SD0: J5.16, U3.53 (QSPI_SD0), U4.5 (SI_SIO0)
/microcontroller/QSPI_SD1: J5.14, U3.55 (QSPI_SD1), U4.2 (SO_SIO1)
/microcontroller/QSPI_SD2: J5.12, U3.54 (QSPI_SD2), U4.3 (WP/_SIO2)
/microcontroller/QSPI_SD3: J5.10, U3.51 (QSPI_SD3), U4.7 (HOLD/_SIO3)
/microcontroller/QSPI_SS: J5.20, R10.2, R11.2, U3.56 (QSPI_SS_N), U4.1 (CS/)
unnamed: C11.2, U3.20 (XIN), Y1.3
unnamed: C12.2, R9.1, Y1.1
unnamed: R9.2, U3.21 (XOUT)
unnamed: R12.2, U3.47 (USB_DP)
unnamed: R15.2, U3.46 (USB_DM)

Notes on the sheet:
supporting circuits
power supply
QSPI debug connector
rp2040 GPIO
SPI flash



Board: 4 copper layers, 50.0 x 50.0 mm, 61 parts (4 on the bottom side), 61 nets.

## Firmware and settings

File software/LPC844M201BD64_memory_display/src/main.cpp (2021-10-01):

/*
 * SPDX-License-Identifier: MIT
 *
 * Copyright (c) 2021 Bart Bilos
 * For conditions of distribution and use, see LICENSE file
 */
/*
 * Example using the sharp memory LCD
 */
#include <nuclone_LPC844M201BD64.hpp>
#include <sharp_memlcd.hpp>

volatile unsigned int systicks = 0;

extern "C" 
{
    void SysTick_Handler(void)
    {
        systicks = systicks + 1;
    }
}

void waitSpiTxComplete(void)
{
    while(!(spiSetGetStatus(SPI0, 0x0) & SPI_STAT_TXRDY))
        ;
}

void lcdTransfer(uint16_t *begin, uint16_t *end)
{
    // transfer of 1
    if(begin+1 == end)
    {
        waitSpiTxComplete();
        spiSetTxCtrlData(SPI0,  SPI_TXDATCTL_TXDAT(*begin) | 
        SPI_TXDATCTL_TXSSEL0 | 
        SPI_TXDATCTL_EOF |
        SPI_TXDATCTL_EOT |
        SPI_TXDATCTL_RXIGNORE | 
        SPI_TXDATCTL_LEN(16) );
        return ;
    }
    // transfer of N
    else
    {
        uint16_t *p = begin;
        while (p < end)
        {
            waitSpiTxComplete();
            spiSetTxCtrlData(SPI0,  SPI_TXDATCTL_TXDAT(*p) | 
            SPI_TXDATCTL_TXSSEL0 | 
            SPI_TXDATCTL_EOF |
            SPI_TXDATCTL_RXIGNORE | 
            SPI_TXDATCTL_LEN(16) );
            p++;
        }
        // line or multiline transfers need to be terminated
        waitSpiTxComplete();
        spiSetTxCtrlData(SPI0,  SPI_TXDATCTL_TXDAT(0x0000) | 
            SPI_TXDATCTL_TXSSEL0 | 
            SPI_TXDATCTL_EOF |
            SPI_TXDATCTL_EOT |
            SPI_TXDATCTL_RXIGNORE | 
            SPI_TXDATCTL_LEN(16) );    
    }
}

util::sharpMemLcd<util::LS013B4DN04, lcdTransfer> boardLcd;

void transferFramebuf(void)
{
    boardLcd.flipVcom();
    boardLcd.lcdUpdate();
}

int main()
{
    unsigned int currticks = systicks;
    boardInit();
    spiSetTxCtrlData(SPI0,  SPI_TXDATCTL_TXDAT(0x4) | 
        SPI_TXDATCTL_TXSSEL0 | 
        SPI_TXDATCTL_EOF |
        SPI_TXDATCTL_RXIGNORE | 
        SPI_TXDATCTL_LEN(3) );
    waitSpiTxComplete();
    spiSetTxCtrlData(SPI0,  SPI_TXDATCTL_TXDAT(0x0000) | 
        SPI_TXDATCTL_TXSSEL0 | 
        SPI_TXDATCTL_EOF |
        SPI_TXDATCTL_EOT |
        SPI_TXDATCTL_RXIGNORE | 
        SPI_TXDATCTL_LEN(16) );
    boardLcd.init();
    while (1) {
        if(currticks < systicks)
        {
            currticks = systicks;
            for(unsigned int i = 0 ; i < boardLcd.maxY; i++)
            {
                for(unsigned int j = 0; j < boardLcd.maxX; j++)
                {
                    boardLcd.putPixel(j, i, ((j ^ i) + currticks) & 0x20);
                    //boardLcd.putPixel(i, j, ((i*i + j*j) + currticks) & 0x20);
                    //if(i == j) boardLcd.putPixel(i, j, 1);
                }
            }
            transferFramebuf();
        }
    }
}

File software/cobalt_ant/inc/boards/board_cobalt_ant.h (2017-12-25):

/*
 * board_cobalt_ant.h
 *
 *  Created on: Dec 24, 2017
 *      Author: abilos
 */

#ifndef INC_BOARDS_BOARD_COBALT_ANT_H_
#define INC_BOARDS_BOARD_COBALT_ANT_H_

#include <chip.h>

// LED
#define LED_PORT	2
#define LED_PIN		9
#define LED_IOCON	IOCON_PIO2_9
// test pads (spare i/o's)
#define	TP1_PORT	0
#define	TP1_PIN		3
#define TP1_IOCON	IOCON_PIO0_3
#define	TP2_PORT	0
#define	TP2_PIN		6
#define TP2_IOCON	IOCON_PIO0_6
#define	TP3_PORT	2
#define	TP3_PIN		8
#define TP3_IOCON	IOCON_PIO2_8
#define	TP4_PORT	2
#define	TP4_PIN		5
#define TP4_IOCON	IOCON_PIO2_5
#define	TP5_PORT	3
#define	TP5_PIN		5
#define TP5_IOCON	IOCON_PIO3_5
#define	TP6_PORT	2
#define	TP6_PIN		6
#define TP6_IOCON	IOCON_PIO2_6
#define	TP7_PORT	2
#define	TP7_PIN		0
#define TP7_IOCON	IOCON_PIO2_0
// GPIO's
#define	GPIO1_PORT	0
#define GPIO1_PIN	2
#define GPIO1_IOCON	IOCON_PIO0_2
#define	GPIO2_PORT	1
#define GPIO2_PIN	8
#define GPIO2_IOCON	IOCON_PIO1_8
#define	GPIO3_PORT	0
#define GPIO3_PIN	5
#define GPIO3_IOCON	IOCON_PIO0_5
#define	GPIO4_PORT	0
#define GPIO4_PIN	4
#define GPIO4_IOCON	IOCON_PIO0_4
#define	GPIO5_PORT	2
#define GPIO5_PIN	7
#define GPIO5_IOCON	IOCON_PIO2_7
#define	GPIO6_PORT	1
#define GPIO6_PIN	9
#define GPIO6_IOCON	IOCON_PIO1_9
#define	GPIO7_PORT	2
#define GPIO7_PIN	2
#define GPIO7_IOCON	IOCON_PIO2_2
#define	GPIO8_PORT	2
#define GPIO8_PIN	3
#define GPIO8_IOCON	IOCON_PIO2_3
#define	GPIO9_PORT	2
#define GPIO9_PIN	1
#define GPIO9_IOCON	IOCON_PIO2_1
// FTDI serial
#define SERIAL_CTS_PORT	0
#define SERIAL_CTS_PIN	7
#define SERIAL_CTS_IOCON	IOCON_PIO0_7
#define SERIAL_RTS_PORT	1
#define SERIAL_RTS_PIN	5
#define SERIAL_RTS_IOCON	IOCON_PIO1_5
#define SERIAL_RXD_PORT	1
#define SERIAL_RXD_PIN	7
#define SERIAL_RXD_IOCON	IOCON_PIO1_7
#define SERIAL_TXD_PORT	1
#define SERIAL_TXD_PIN	6
#define SERIAL_TXD_IOCON	IOCON_PIO1_6
// SPI FLASH
#define FLASH_SCK_PORT	2
#define FLASH_SCK_PIN	11
#define FLASH_SCK_IOCON	IOCON_PIO2_11
#define FLASH_CE_PORT	2
#define FLASH_CE_PIN	10
#define FLASH_CE_IOCON	IOCON_PIO2_10
#define FLASH_MOSI_PORT	0
#define FLASH_MOSI_PIN	9
#define FLASH_MOSI_IOCON	IOCON_PIO0_9
#define FLASH_MISO_PORT	0
#define FLASH_MISO_PIN	8
#define FLASH_MISO_IOCON	IOCON_PIO0_8
// I2C breakout
// SPI breakout
//



void boardCobaltAntInit(void);



#endif /* INC_BOARDS_BOARD_COBALT_ANT_H_ */

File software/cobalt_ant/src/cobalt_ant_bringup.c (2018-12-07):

/*
 * @brief Blinky example using timers and sysTick
 *
 * @note
 * Copyright(C) NXP Semiconductors, 2012
 * All rights reserved.
 *
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
 * @par
 * Permission to use, copy, modify, and distribute this software and its
 * documentation is hereby granted, under NXP Semiconductors' and its
 * licensor's relevant copyrights in the software, without fee, provided that it
 * is used in conjunction with NXP Semiconductors microcontrollers.  This
 * copyright, permission, and disclaimer notice must appear in all copies of
 * this code.
 */

#include <chip.h>
#include <stdio.h>
#include <board.h>
#include <print.h>
#include <ringbuffers.h>
#include <cmdline.h>
#include <ticks.h>
#include <strdata.h>
#include <driver_W25Q32BV.h>
#include <cmdline_commands.h>
#include <logfs.h>


/*****************************************************************************
 * Private types/enumerations/variables
 ****************************************************************************/

char CmdlineHistoryBuffer[128];
t_queueString CmdlineHistory = {.len = sizeof(CmdlineHistoryBuffer)-1, .head = 0, .tail = 0, .data = CmdlineHistoryBuffer};


/*****************************************************************************
 * Public types/enumerations/variables
 ****************************************************************************/

/*****************************************************************************
 * Private functions
 ****************************************************************************/

/*****************************************************************************
 * Public functions
 ****************************************************************************/

void UART_IRQHandler(void)
{
	Chip_UART_IRQRBHandler(LPC_USART, &rxring, &txring);
}

/**
 * @brief	main routine for blinky example
 * @return	Function should not exit.
 */
int main(void)
{
	uint32_t current_systick = 0;
	ticksSet(0);
	SystemCoreClockUpdate();
	promptInit(&CmdlineHistory);

	/* Enable and setup SysTick Timer at a periodic rate */
	SysTick_Config(SystemCoreClock / SYSTICKS_PER_S);

	flashInit();
	fsInit();

	while (1) {
		// blink the led to show the device works
		if((current_systick + SYSTICKS_PER_S/4) < systick)
		{
			current_systick = systick;
			Chip_GPIO_SetPinToggle(LPC_GPIO, LED_PORT, LED_PIN);
		}
		promptProcess(cmdLineEntries);
	}

	return 0;
}

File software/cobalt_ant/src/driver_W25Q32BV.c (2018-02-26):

/*
 * driver_W25Q32BV.c
 *
 *  Created on: Dec 25, 2017
 *      Author: abilos
 */

#include <stdbool.h>
#include <driver_W25Q32BV.h>
#include <chip.h>
#include <board.h>
#include <results.h>
#include <sqstring.h>

#define	JEDEC_MANU_WINBOND	0xEF
#define	W25Q32BV_MAX_ADDR	(4194304u)
#define	W25Q32BV_MAX_PAGE	(16384u)
#define	W25Q32BV_MAX_SECT	(1024u)
#define	W25Q32BV_MAX_BLK	(64u)

#define	W25Q32BV_STAT1_BUSY	(0x01)
#define	W25Q32BV_STAT1_WEL	(0x02)

/*****************************************************************************
 * Private types/enumerations/variables
 ****************************************************************************/
const uint8_t	W25Q32BVCmdJedecID[] = {0x9F};
const uint8_t 	W25Q32BVCmdRead[] = {0x03};
const uint8_t 	W25Q32BVCmdReadStatus1[] = {0x05};
const uint8_t 	W25Q32BVCmdReadStatus2[] = {0x35};
const uint8_t 	W25Q32BVCmdWriteEnable[] = {0x06};
const uint8_t 	W25Q32BVCmdWriteDisable[] = {0x04};
const uint8_t 	W25Q32BVCmdPageProgram[] = {0x02};
const uint8_t 	W25Q32BVCmdEraseSect[] = {0x20};
const uint8_t   W25Q32BVJedecID[] = {JEDEC_MANU_WINBOND, 0x40, 0x16};

/*****************************************************************************
 * Public types/enumerations/variables
 ****************************************************************************/

/*****************************************************************************
 * Private functions
 ****************************************************************************/

/*****************************************************************************
 * Public functions
 ****************************************************************************/

void flashEnable()
{
	Chip_GPIO_SetPinOutLow(LPC_GPIO, FLASH_CE_PORT, FLASH_CE_PIN);
}

void flashDisable()
{
	Chip_GPIO_SetPinOutHigh(LPC_GPIO, FLASH_CE_PORT, FLASH_CE_PIN);
}


result flashInit()
{
	flashEnable();
	Chip_SSP_WriteFrames_Blocking(LPC_SSP0, W25Q32BVCmdJedecID, sizeof(W25Q32BVCmdJedecID));
	uint8_t jedecID[3];
	Chip_SSP_ReadFrames_Blocking(LPC_SSP0, jedecID, sizeof(jedecID));
	flashDisable();
	// check jedec ID
	if(sqmemcmp(jedecID, W25Q32BVJedecID, sizeof(W25Q32BVJedecID)) == 0)
		return noError;
	else
		return flashUnknownId;
}

result flashRead(uint32_t address, void *s, uint32_t n)
{
	// TODO Assert macro here, this should not happen!
	if((address + n) > W25Q32BV_MAX_ADDR)
		return flashInvalidAddr;
	uint8_t flashAddress[3] = {address>>16, address>>8, address};
	flashEnable();
	Chip_SSP_WriteFrames_Blocking(LPC_SSP0, W25Q32BVCmdRead, sizeof(W25Q32BVCmdRead));
	Chip_SSP_WriteFrames_Blocking(LPC_SSP0, flashAddress, sizeof(flashAddress));
	Chip_SSP_ReadFrames_Blocking(LPC_SSP0, s, n);
	flashDisable();
	return noError;
}

bool flashBusy()
{
	uint8_t status1;
	flashEnable();
	Chip_SSP_WriteFrames_Blocking(LPC_SSP0, W25Q32BVCmdReadStatus1, sizeof(W25Q32BVCmdReadStatus1));
	Chip_SSP_ReadFrames_Blocking(LPC_SSP0, &status1, sizeof(status1));
	flashDisable();
	if(status1 & W25Q32BV_STAT1_BUSY)
		return true;
	else
		return false;
}

void flashWriteEnable(bool enable)
{
	flashEnable();
	if(enable)
		Chip_SSP_WriteFrames_Blocking(LPC_SSP0, W25Q32BVCmdWriteEnable, sizeof(W25Q32BVCmdWriteEnable));
	else
		Chip_SSP_WriteFrames_Blocking(LPC_SSP0, W25Q32BVCmdWriteDisable, sizeof(W25Q32BVCmdWriteDisable));
	flashDisable();
}

result flashWrite(uint32_t address, void *s, uint32_t n)
{
	// TODO Assert macro here, this should not happen!
	if((address + n) > W25Q32BV_MAX_ADDR)
		return flashInvalidAddr;
	uint8_t flashAddress[3] = {address>>16, address>>8, address};
	uint32_t ready_count = 0;

	// page program
	flashWriteEnable(true);
	flashEnable();
	Chip_SSP_WriteFrames_Blocking(LPC_SSP0, W25Q32BVCmdPageProgram, sizeof(W25Q32BVCmdPageProgram));
	Chip_SSP_WriteFrames_Blocking(LPC_SSP0, flashAddress, sizeof(flashAddress));
	Chip_SSP_WriteFrames_Blocking(LPC_SSP0, s, n);
	flashDisable();

	while(flashBusy())
		ready_count++;
	flashWriteEnable(false);
	return noError;
}

result flashEraseSector(uint32_t address)
{
	uint32_t ready_count = 0;
	uint8_t flashAddress[3] = {address>>16, address>>8, address};
	flashWriteEnable(true);
	flashEnable();
	Chip_SSP_WriteFrames_Blocking(LPC_SSP0, W25Q32BVCmdEraseSect, sizeof(W25Q32BVCmdEraseSect));
	Chip_SSP_WriteFrames_Blocking(LPC_SSP0, flashAddress, sizeof(flashAddress));
	flashDisable();

	while(flashBusy())
		ready_count++;
	return noError;
}

result flashEraseBlock(uint32_t block)
{
	return noError;
}

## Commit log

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2016-11-03 * started with mechanical bits of the squantlogger base, connectors and bits
    [squantlogger_base.kicad_pcb, squantlogger_base.sch]
2016-11-03 * added .gitignore * updated schematic for squantlogger_base
    [squantlogger_base.sch]
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2017-01-23 * started schematic of the chrome hedgehog board
    [squantlogger_chrome_hedgehog.kicad_pcb, squantlogger_chrome_hedgehog.sch]
2017-05-21 * added new mini datalogger called Cobalt Ant
    [squantlogger_cobalt_ant.kicad_pcb, squantlogger_cobalt_ant.sch]
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2017-06-08 * some further work on the cobalt ant datalogger
    [squantlogger_cobalt_ant.kicad_pcb, squantlogger_cobalt_ant.sch]
2017-06-20 * started fleshing out the schematic of the squantlogger
    [squantlogger_cobalt_ant.kicad_pcb, squantlogger_cobalt_ant.sch]
2017-06-29 * removed kicad caches from ignore list, they seem to resolve lots of rebuilding issues when others check out your pcb
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2017-06-29 * added some more schematic connections to the breakout headers
    [squantlogger_cobalt_ant.sch]
2017-06-29 * lots of smaller updates due to DRC errors * used powerjoiner component to connect analog and digital powerdomains * DAMN, not enough pins, I really need to get TQFP48 pin controller, but it is very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
    [squantlogger_cobalt_ant.sch]
2017-06-29 * reimported most components * switched to 4 layer board, we shall see if I really REALLY need it
    [squantlogger_cobalt_ant.kicad_pcb]
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2017-07-09 * done with schematic, now layout of the board, its going to be fun...
    [squantlogger_cobalt_ant.kicad_pcb, squantlogger_cobalt_ant.sch]
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2017-10-01 * some further layouting on the pcb, * changed some component footprints to make layout more manageable
    [squantlogger_cobalt_ant.kicad_pcb, squantlogger_cobalt_ant.sch]
2017-10-01 * added series resistors to all the off board pads like ADC's and GPIO's * started routing with the push and shove router, maybe need to redo that but more manual work
    [squantlogger_cobalt_ant.kicad_pcb, squantlogger_cobalt_ant.sch]
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2017-10-31 * small schematic updates * ripped up all traces and comitted to also placing components on the bottom layer
    [squantlogger_cobalt_ant.kicad_pcb, squantlogger_cobalt_ant.sch]
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2017-11-19 * added some test pads on some spare I/O's * changed led footprint
    [squantlogger_cobalt_ant.sch]
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2017-11-19 * some small track positioning improvemens * fixed some small silkscreen clashes
    [squantlogger_cobalt_ant.kicad_pcb]
2017-11-19 * again a silkscreen clash fix * moved version number
    [squantlogger_cobalt_ant.kicad_pcb]
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2017-11-20 * small silk fixes * moved further away from center mounting hole
    [squantlogger_cobalt_ant.kicad_pcb, squantlogger_cobalt_ant.sch]
2017-11-20 * one small silkscreen fix
    [squantlogger_cobalt_ant.kicad_pcb]
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2017-12-24 * fixed and made everything Makefile compatible * renamed some board support stuff
    [board_cobalt_ant.h, cobalt_ant_bringup.c]
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2018-02-18 * ported to new streams subsystem for stdin and stdout * fixed a warning in the spi flash driver
    [cobalt_ant_bringup.c]
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2018-02-25 * added sector erase command to flash driver * fixed a few renaming mistakes
    [driver_W25Q32BV.c]
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2018-02-25 * fixed mistake in erase sector
    [driver_W25Q32BV.c]
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2018-06-30 reworked nicked beetle breakout
    [nickel_beetle_breakout.kicad_pcb, nickel_beetle_breakout.sch]
2018-06-30 fixed PCB layout
    [nickel_beetle_breakout.kicad_pcb]
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2018-10-13 added _autosave to gitignores updated chrome bee project while messing about with net ties changed the symbol and footprint tables
    [chrome_bee_lpc824.kicad_pcb, chrome_bee_lpc824.sch]
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2019-01-24 forgotten cache file, added lipo test board for hammond 1551G development board
    [hammond_1551G_devboard_Lipo_charger.kicad_pcb, hammond_1551G_devboard_Lipo_charger.sch]
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2019-01-27 tried out if component copper graphics will get cleared by the plane fill algorithm
    [hammond_1551G_devboard_Lipo_charger.kicad_pcb]
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2019-01-27 replaced JST PH connectors by SMD variants so they stack better, needed to redo layout altough :(
    [hammond_1551G_devboard_Lipo_charger.kicad_pcb, hammond_1551G_devboard_Lipo_charger.sch]
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2019-01-27 ported over the lipo charger test and added a LPC824, redone schematic completely
    [chrome_bee_lpc824.kicad_pcb, chrome_bee_lpc824.sch]
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2019-01-30 removed jtag, added proto area so a lpc824 protoboard can be fitted
    [hammond_1551G_devboard_Lipo_charger.kicad_pcb]
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2019-02-10 replaced regulator by SOT-23 variant, renamed the input power connector net to VIN and use the switched battery power as VBUS
    [hammond_1551G_devboard_Lipo_charger.kicad_pcb, hammond_1551G_devboard_Lipo_charger.sch]
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2019-02-21 fix, library update Fixed wrong mosfet in lipocharger, pinout is still fine. updated to newer component library
    [hammond_1551G_devboard_Lipo_charger.kicad_pcb, hammond_1551G_devboard_Lipo_charger.sch]
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2019-03-01 board setup Updated board setup as there is a mistake for crystal oscillator setup
    [board.cpp, main.cpp]
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2019-07-18 added ADC pins, added additional commands, reworked pin handling
    [main.cpp, proto_v2.hpp]
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2019-09-17 removed input capacitor as PSU is close to the input cap anyway
    [nuclone_powersupply.sch]
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2019-09-23 wrong pull polarity for i2c fixed
    [nuclone_mcu_LPC812M101JD20.sch]
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2019-10-26 fixed newer nuclone connector library
    [nuclone_LPC812M101JDH20.sch]
2019-10-26 fixed DRC issue, passes DRC now
    [nuclone_LPC812M101JDH20.kicad_pcb]
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2019-10-27 cleanup of old cruft on board, updated LPC package, initial component placement
    [nuclone_LPC824M201JHI33.kicad_pcb, nuclone_LPC824M201JHI33.sch]
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2019-11-21 fixed some mixed pins in the resistor networks
    [nuclone_tester_medium.sch]
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2019-12-06 further pinning layout, need to fix some orderings
    [nuclone_LPC1125JBD48-303.kicad_pcb, nuclone_LPC1125JBD48-303.sch]
2019-12-06 fixing pinouts
    [nuclone_LPC1125JBD48-303.sch]
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2019-12-25 fixing one missed GPIO
    [nuclone_LPC1125JBD48-303.kicad_pcb, nuclone_LPC1125JBD48-303.sch]
2019-12-25 further fixed missed GPIO and more sensible distribution
    [nuclone_LPC1125JBD48-303.kicad_pcb, nuclone_LPC1125JBD48-303.sch]
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2020-01-03 fixed schematic remains
    [nuclone_LPC1125JBD48-303.sch]
2020-01-03 fixed some ERC issues
    [nuclone_LPC1125JBD48-303.sch]
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2020-01-17 flipped pin designations to top layer
    [nuclone_LPC824M201JHI33.kicad_pcb]
2020-01-17 fixing mistakes with pinouts
    [nuclone_LPC824M201JHI33.kicad_pcb, nuclone_LPC824M201JHI33.sch]
2020-01-17 pinning now correct
    [nuclone_LPC824M201JHI33.kicad_pcb, nuclone_LPC824M201JHI33.sch]
2020-01-17 placement changes, fixed connection mistake
    [nuclone_LPC824M201JHI33.kicad_pcb, nuclone_LPC824M201JHI33.sch]
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2020-01-17 renamed all pins to their correct designation
    [nuclone_LPC824M201JHI33.kicad_pcb]
2020-01-17 replaced missing pin designators
    [nuclone_LPC824M201JHI33.kicad_pcb]
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2020-11-03 swapped uart pins to make it easier to route
    [nuclone_LPC824M201JHI33_expansion_serial_flash.sch]
2020-11-03 swapped uart pins again, as it is better ;-)
    [nuclone_LPC824M201JHI33_expansion_serial_flash.sch]
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2020-11-04 added ERC fixes
    [nuclone_LPC824M201JHI33_expansion_serial_flash.sch]
2020-11-04 initial placement and some beginning of routing, but need to make it more compact
    [nuclone_LPC824M201JHI33_expansion_serial_flash.kicad_pcb]
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2020-11-06 fixed DRC error
    [nuclone_LPC824M201JHI33_expansion_serial_flash.kicad_pcb]
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2020-11-06 added new pcb library, removed old bits from microSD card expansion (adapted from serial flash expansion)
    [nuclone_LPC824M201JHI33_expansion_microSD_card.sch]
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2020-11-08 changed the shield attachment of the microSD socket, added some labels to the UART connection
    [nuclone_LPC824M201JHI33_expansion_microSD_card.kicad_pcb]
2020-11-08 added fixes to SD card socket
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2020-11-16 copied over nuclone LPC1114 to new LPC1125 nuclone, will remove the old one
    [nuclone_LPC1125JBD48.kicad_pcb, nuclone_LPC1125JBD48.sch]
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2020-11-17 some schematic part movements, sectioning of bits and pieces, added jumpers for VREFP/VREFN, added some more reset bits
    [nuclone_LPC1125JBD48.sch]
2020-11-17 added decoupling around reset
    [nuclone_LPC1125JBD48.sch]
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2020-11-17 added missed footprint for the LED
    [nuclone_LPC1125JBD48.sch]
2020-11-17 fixed label on a jumper
    [nuclone_LPC1125JBD48.sch]
2020-11-17 fixed wrong footprint
    [nuclone_LPC1125JBD48.sch]
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2020-12-02 fixed labels on jumpers, made a section block for the microcontroller
    [nuclone_LPC1114JBD48.sch]
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2020-12-04 placed, routed, the reset led indication circuit
    [nuclone_LPC1125JBD48.kicad_pcb]
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2020-12-05 fixed GPIO silk labels, moved around jumper labels
    [nuclone_LPC1125JBD48.kicad_pcb]
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2020-12-06 minor fixes in schematic, initial placement of all components, all ERC checks pass
    [nuclone_LPC845M301JBD48.kicad_pcb, nuclone_LPC845M301JBD48.sch]
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2020-12-10 jumper labels fixed
    [nuclone_LPC845M301JBD48.kicad_pcb]
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2020-12-10 label alignment on left connector fixed
    [nuclone_LPC845M301JBD48.kicad_pcb]
2020-12-10 updated pin labels and fixed alignment
    [nuclone_LPC845M301JBD48.kicad_pcb]
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2020-12-15 fixed small silkscreen mistake
    [nuclone_LPC1125JBD48.kicad_pcb]
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2020-12-21 corrected error in pin definition of activity led
    [board.hpp, main.cpp]
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2020-12-29 reverting class definition, checking size
    [main.cpp]
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2021-02-04 changing LPC812 nuclone to be easier to produce and some additional features
    [nuclone_LPC812M101JDH20.sch]
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2021-02-04 small fixes
    [nuclone_LPC812M101JDH20.sch]
2021-02-05 added medium nuclone baseplate and a medium nuclone cover that can hold one expansion board
    [medium_nuclone_base_plate.FCStd, medium_nuclone_base_plate_m3_tapping.stl, medium_nuclone_cover_expansion.FCStd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]
2021-02-05 fixed error with the sizing of the box, there are two walls per box instead of one ;-)
    [medium_nuclone_base_plate.FCStd, medium_nuclone_base_plate_m3_tapping.stl, medium_nuclone_cover_expansion.FCStd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]
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2021-02-18 fixed board label
    [nuclone_LPC812M101JDH20.sch]
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2021-04-03 fixed pinning on external GPIO port
    [nuclone_LPC844M201BD64.sch]
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2021-04-05 updated PCB library, fixed PQFP64
2021-04-05 updated to fixed QFP package
    [nuclone_LPC844M201BD64.kicad_pcb]
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2021-04-25 applied fixed LPC84X QFP64
    [nuclone_LPC844M201BD64.sch]
2021-04-25 updated versionnumber, changed via sizes, fixed VDD/VSS swap
    [nuclone_LPC844M201BD64.kicad_pcb]
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2021-07-04 added test points to SWD connections, added bootload button, removed series resistors of SWD
    [nuclone_LPC844M201BD64.sch]
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2021-07-04 add RESET test pad
    [nuclone_LPC844M201BD64.sch]
2021-07-04 removed reset LED
    [nuclone_LPC844M201BD64.sch]
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2021-10-01 using flip command from lcd library
    [main.cpp]
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2021-11-21 switched LPC812 nuclone to stacked headers and added pullups to I2C pins
    [microcontroller.sch, nuclone_LPC812M101JDH20.kicad_pcb, nuclone_LPC812M101JDH20.sch]
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2021-11-24 WIP conversion to stacked header, changing right hand header to different format
    [nuclone_STM32F030K6.kicad_pcb, nuclone_STM32F030K6.sch]
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2022-03-03 fixed DRC error, updated versionnumber
    [microcontroller.sch, nuclone_LPC824M201JHI33.sch]
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2022-03-04 fixed labels
    [nuclone_LPC824M201JDH20.kicad_pcb]
2022-03-04 fixed labels and added labels
    [nuclone_LPC824M201JHI33.kicad_pcb]
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2022-05-07 fixed wrong labels
    [nuclone_LPC824M201JHI33.kicad_pcb]
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2022-05-29 updated missing footprint
    [microcontroller.kicad_sch, nuclone_RP2040.kicad_sch]
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2022-05-30 fixed pinout labels
    [nuclone_LPC804M101JHI33.kicad_pcb]
2022-05-30 updated design rules, fixed some DRC errors
    [nuclone_RP2040.kicad_pcb]
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2022-07-04 further routing, added a QSPI debug connector for easy probing with logic analyser
    [microcontroller.kicad_sch, nuclone_RP2040.kicad_pcb, nuclone_RP2040.kicad_sch]
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2023-01-28 preparing to move all VDD nets to another layer so we can change all planes to ground planes
    [nuclone_RP2040.kicad_pcb]
2023-01-28 silk fixes
    [nuclone_RP2040.kicad_pcb]
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2023-01-29 missed save
    [nuclone_RP2040_WSON.kicad_pcb]
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2023-02-05 ERC passes without errors, DRC without errors and warnings, updated versionnumber
    [microcontroller.kicad_sch, nuclone_RP2040_SON.kicad_pcb, nuclone_RP2040_SON.kicad_sch]
2023-02-05 fixed SOIC RP2040 nuclone errors
    [microcontroller.kicad_sch, nuclone_RP2040_SOIC.kicad_pcb, nuclone_RP2040_SOIC.kicad_sch]
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2023-02-06 fixed DRC errors, updated versionnumber
    [microcontroller.kicad_sch, nuclone_RP2040_SOIC.kicad_pcb, nuclone_RP2040_SOIC.kicad_sch]
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2023-02-11 updated versionnumber, fixed silk positioning
    [microcontroller.kicad_sch, nuclone_RP2040_SOIC.kicad_pcb, nuclone_RP2040_SOIC.kicad_sch]
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2023-08-01 WIP schematic entry: added reset control/detection and power control/detection
    [nuclone_small_JTAG_tryout.kicad_pcb, nuclone_small_JTAG_tryout.kicad_sch]
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2023-09-13 fixed DRC/ERC
    [nuclone_small_libmcull_tester.kicad_pcb, nuclone_small_libmcull_tester.kicad_sch]
2023-09-15 fixed some routing
    [nuclone_small_libmcull_tester.kicad_pcb, nuclone_small_libmcull_tester.kicad_sch]
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2024-01-17 fixed DRC errors
    [nuclone_pi_pico_direct.kicad_pcb]
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2024-02-11 fixed pinouts
    [microcontroller.kicad_sch, nuclone_pi_pico_direct.kicad_pcb, nuclone_pi_pico_direct.kicad_sch]
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2024-02-18 prepped nuclone with pi pico module with direct USB connection for production
    [nuclone_pi_pico_direct.kicad_pcb, nuclone_pi_pico_direct.kicad_sch]
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2024-03-06 fixed error with EN pin of raspberry pi pico, respin required
    [microcontroller.kicad_sch, nuclone_pi_pico_USB-c.kicad_pcb, nuclone_pi_pico_direct.kicad_pcb]
2024-03-08 moved RP2040 module so it does not collide with SWD/JTAG connector
    [microcontroller.kicad_sch, nuclone_RP2040_aliexpress.kicad_pcb]
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2024-04-24 reviewed and small fixes
    [nuclone_RP2040_aliexpress.kicad_pcb, nuclone_RP2040_aliexpress.kicad_sch]
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2024-06-28 updated versions, fixed DRC's
    [nuclone_LPC845M301BD48_medium.kicad_pcb, nuclone_LPC845M301BD48_medium.kicad_sch]
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2024-07-05 fixed DRC error and some silk placement
    [microcontroller.kicad_sch, nuclone_LPC845M301BD48_small.kicad_pcb]
2024-07-05 fixed ERC error
    [microcontroller.kicad_sch]
2024-07-07 fixed DRC errors and verified everything
    [nuclone_LPC804M101DH24.kicad_pcb]
2024-07-07 added crystal oscillator
    [microcontroller.kicad_sch, nuclone_LPC804M101DH24.kicad_pcb]
2024-07-07 replace crystal to something easier to solder
    [microcontroller.kicad_sch, nuclone_LPC845M301BD48_small.kicad_pcb]
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
